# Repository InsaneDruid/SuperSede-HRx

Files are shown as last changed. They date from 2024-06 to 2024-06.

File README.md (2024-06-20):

# SuperSede-HRx - a HRx clone family
A 100% compatible replica of the HR40, HR40B &amp; HR80 graphics boards for the CBM PET lineup.

The SuperSede HRx are 100% compatible clones of the HR40, HR40B and HR80 graphics boards for the PET/CBM series computers from 1982, beginning with the dynamic board.
They implements all the features, including the high 320*200 pixel high resolution graphics that can be mixed standard text output on a per character base, the availability of the 8k of onboard RAM for Data usage and the possibility to use existing ROM expansion on the graphics board.

## The HR40 board for the non CRTC 40column dynamic PET lineup
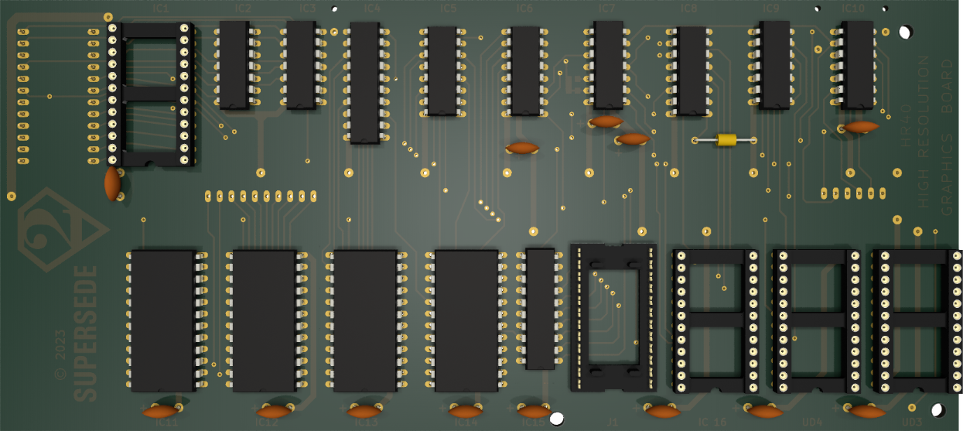
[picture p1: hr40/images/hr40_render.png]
HR40 render


[Schematic](https://github.com/InsaneDruid/SuperSede-HRx/blob/main/hr40/hr40.pdf "Schematic")  

[Bill of Materials](https://htmlpreview.github.io/?https://github.com/InsaneDruid/SuperSede-HRx/blob/main/hr40/bom/hr40_bom.html "Bill of Materials")

[Wire connections](https://github.com/InsaneDruid/SuperSede-HRx/blob/main/hr40/hr40_connections.pdf "Wire connections" )

* The connection to the Character ROM can be made with a standard DIP24 to ribbon cable adapter.

* The connection to UF8 can be made with the provided breakout adapter found in [adapter_uf8](https://github.com/InsaneDruid/SuperSede-HRx/blob/main/adapter_uf8/ "adapter_uf8").

## The HR40b board for the CRTC based 40column PET/CBM lineup
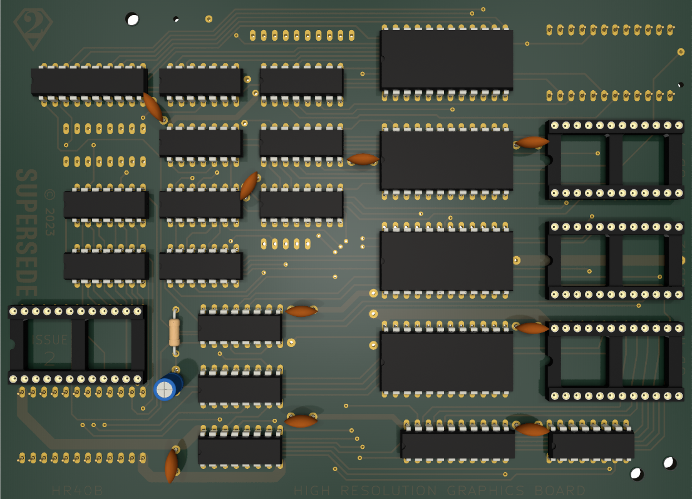
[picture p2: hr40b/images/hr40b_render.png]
HR40B render


[Schematic](https://github.com/InsaneDruid/SuperSede-HRx/blob/main/hr40b/hr40b.pdf "Schematic")  

[Bill of Materials](https://htmlpreview.github.io/?https://github.com/InsaneDruid/SuperSede-HRx/blob/main/hr40b/bom/hr40b_bom.html "Bill of Materials")

[Wire connections](https://github.com/InsaneDruid/SuperSede-HRx/blob/main/hr40b/hr40b_connections.pdf "Wire connections" )

* The connection to the CRTC can be made with the provided breakout adapter found in [adapter_crtc](https://github.com/InsaneDruid/SuperSede-HRx/blob/main/adapter_crtc/ "adapter_crtc").

## The HR80 board for the 80column CBM lineup (8032, 8032SK*, 8096)
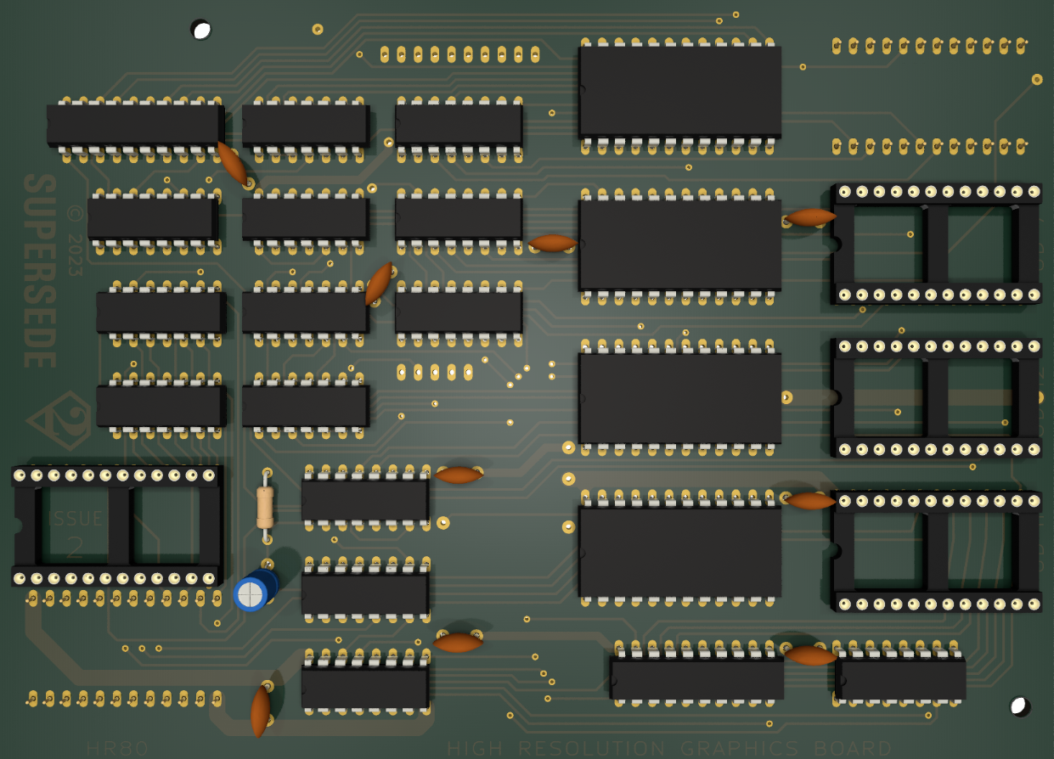
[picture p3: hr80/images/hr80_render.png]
HR80 render


[Schematic](https://github.com/InsaneDruid/SuperSede-HRx/blob/main/hr80/hr80.pdf "Schematic")  

[Bill of Materials](https://htmlpreview.github.io/?https://github.com/InsaneDruid/SuperSede-HRx/blob/main/hr80/bom/hr80_bom.html "Bill of Materials")

[Wire connections](https://github.com/InsaneDruid/SuperSede-HRx/blob/main/hr80/hr80_connections.pdf "Wire connections" )

* The connection to the CRTC can be made with the provided breakout adapter found in [adapter_crtc](https://github.com/InsaneDruid/SuperSede-HRx/blob/main/adapter_crtc/ "adapter_crtc").

## The SuperSede cards and Expansion ROMs
The SuperSede boards hav 8k of their own RAM which occupies memory locations 36864 to 45055 ($9000 to $AFFF). This is the Rom Expansion area, normally represented by sockets UD11 and UD12 (UD3 and UD4 for 9-inch PETs). 

When you power-up your computer the ROM sockets are enabled and the high resolution memory disabled. Thus Rom expansions can be used in standard text mode like normal.

## The Firmware
The firmware needed for the SuperSede cards consist of

* A modified CharRom (with inverted characters).
* A 4k ROM containing the EditorROM followed by the GRAPHIX software in the E900-EFFF area.

The Firmware and supporting tools are available on their own repository: [SuperSede-HRx-Software](https://github.com/InsaneDruid/SuperSede-HRx-Software/ "Firmware and tools for the SuperSede HRx boards ")

## The License
This work is licensed under a Creative Commons Attribution-ShareAlike 4.0 International License.   
See https://creativecommons.org/licenses/by-sa/4.0/.

## The Credits
This work would not have been possible without the help from a bunch of amazing people from [VzEkC e. V. forums](https://forum.classic-computing.de/forum/ "forum.classic-computing.de"). Many thanks go out to:

* *Andy Grady* - for the scans of a blank board that formed the backbone for this project, the construction of the first prototypes as well as writing the print routines and assembling the firmware for the cards.
* *Steve Gray* - for collecting a ton of information about the cards
* *CBM_Ba* and *Richy* - for prototyping, testing, feedback and general positive retrocomputing craziness

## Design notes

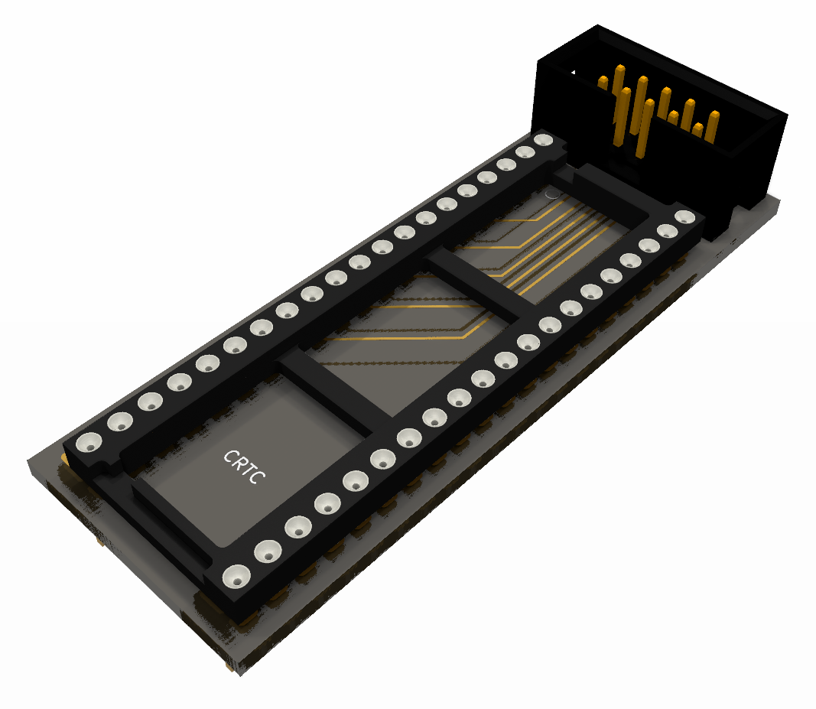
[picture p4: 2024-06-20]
adapter_crtc/images/adapter_crtc_render.png

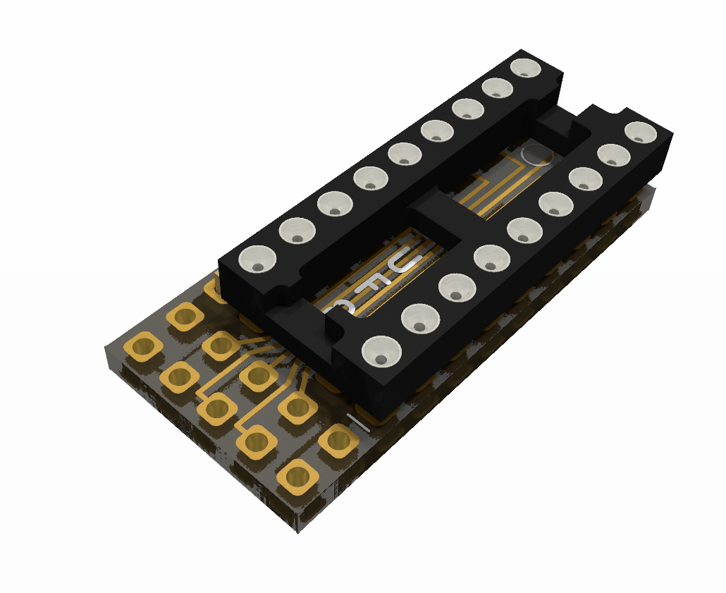
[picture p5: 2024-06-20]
adapter_uf8/images/adapter_uf8_render.png

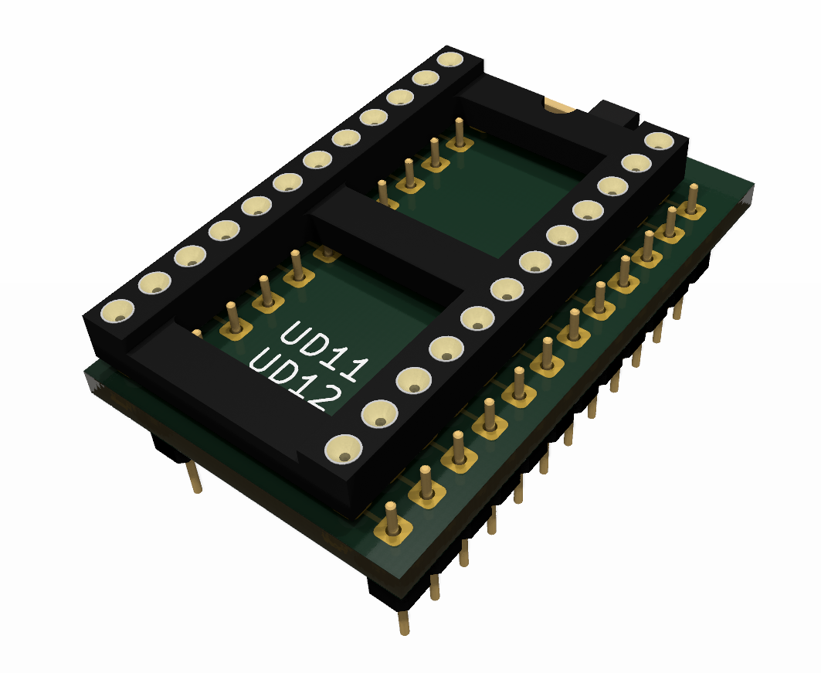
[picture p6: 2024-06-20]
adapter_roms_sk/images/adapter_roms_sk_render.png

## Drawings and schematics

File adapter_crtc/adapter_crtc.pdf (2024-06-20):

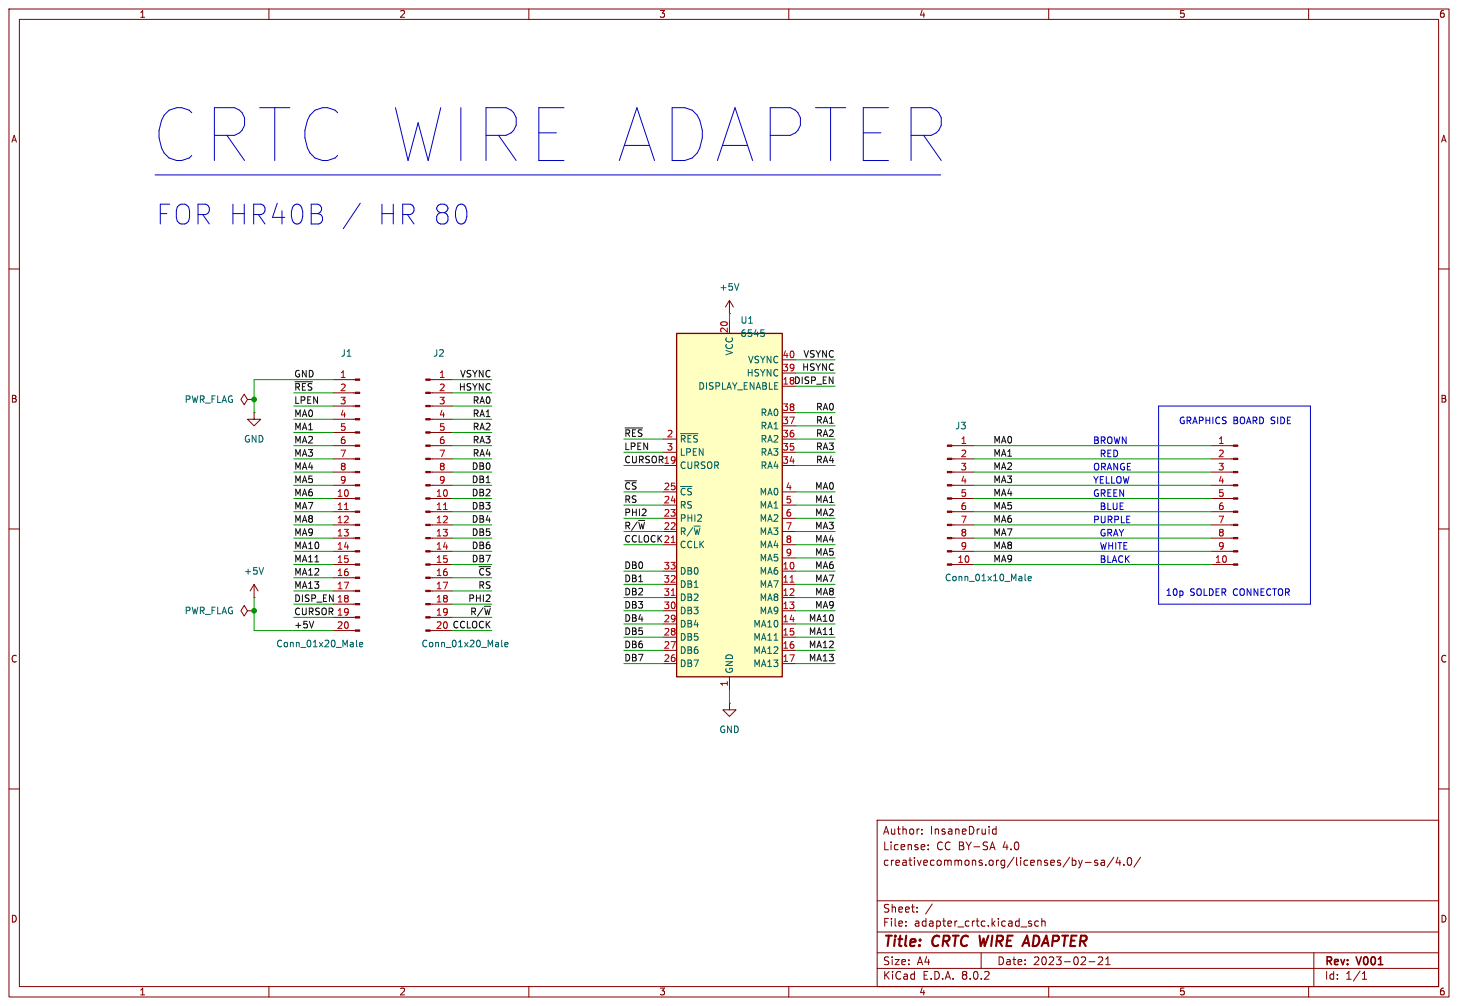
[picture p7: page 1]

BROWN CRTC WIRE ADAPTER

1 MA6 10 MA7 11 MA8 12 MA9 13 MA10 14 MA11 15 MA12 16 MA13 17 DISPLAY_ENABLE 18 CURSOR 19 ~{RES} 2 VCC 20 CCLK 21 R/~{W} 22 PHI2 23 RS 24 ~{CS} 25 DB7 26 DB6 27 DB5 28 DB4 29

Id: 1/1 Title: CRTC WIRE ADAPTER

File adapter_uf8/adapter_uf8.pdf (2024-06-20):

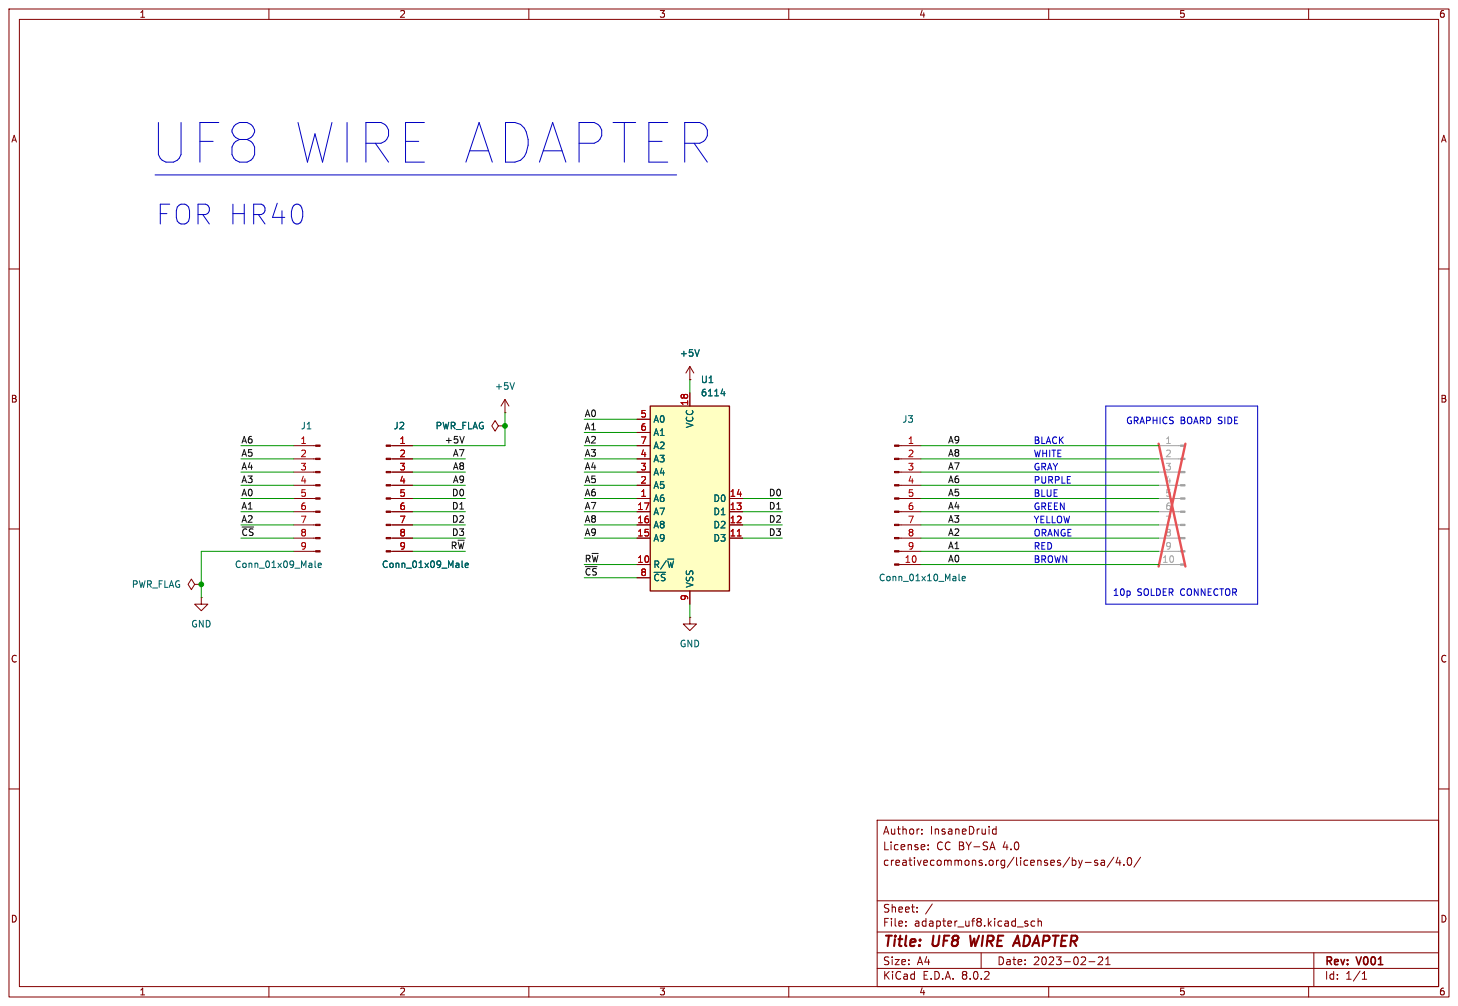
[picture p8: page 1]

10p SOLDER CONNECTOR GRAPHICS BOARD SIDE WHITE
BLACK

Id: 1/1 Title: UF8 WIRE ADAPTER

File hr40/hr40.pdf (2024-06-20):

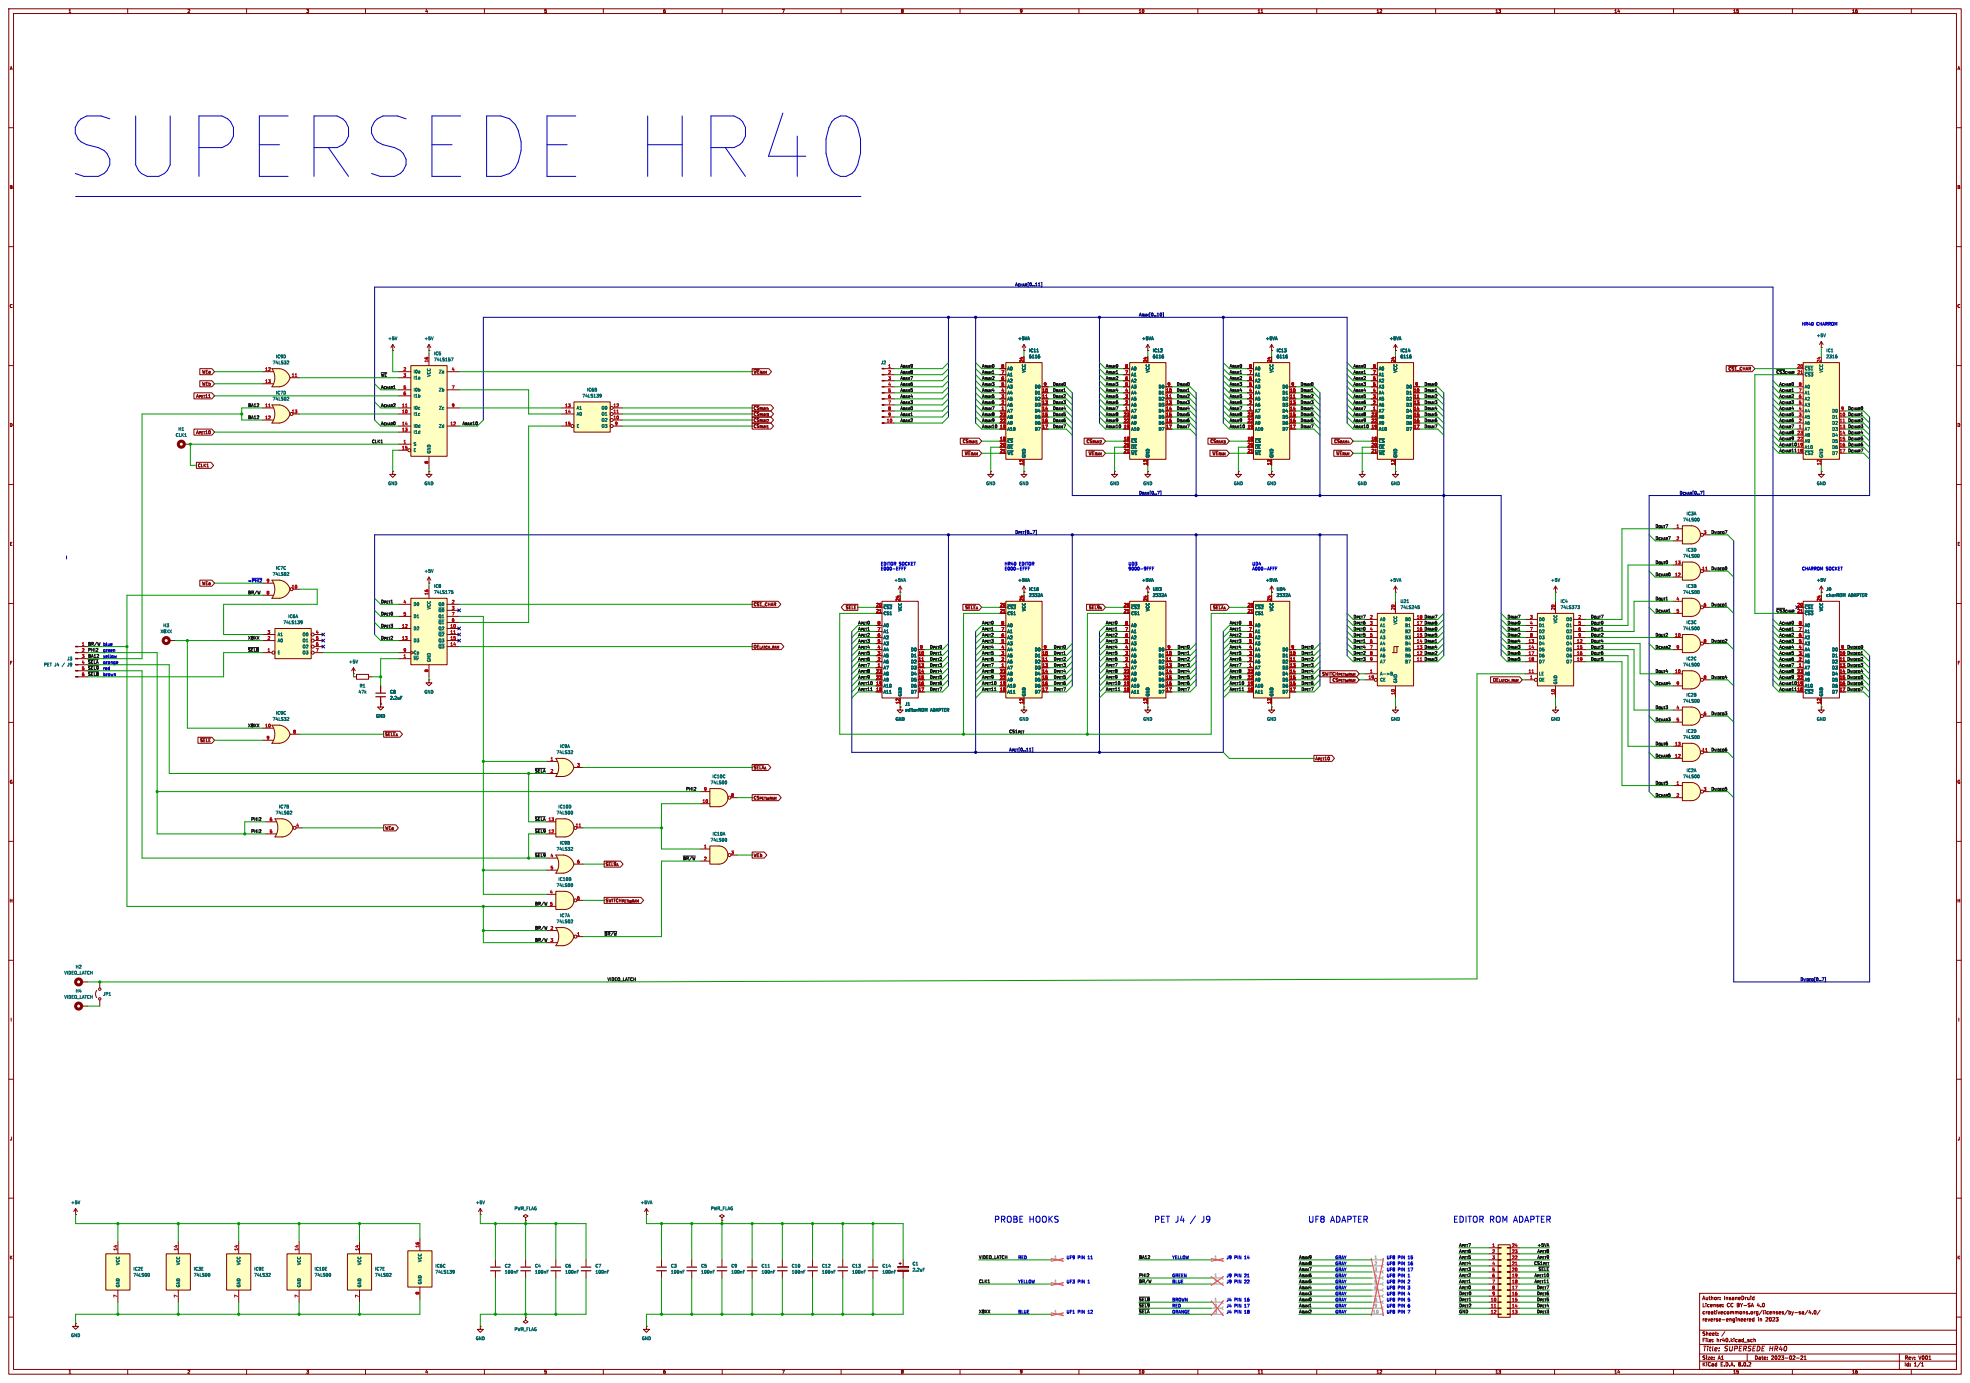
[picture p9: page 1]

UF3 PIN 1 RED PROBE HOOKS

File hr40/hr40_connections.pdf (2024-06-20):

# SUPERSEDE HR40 wire connections

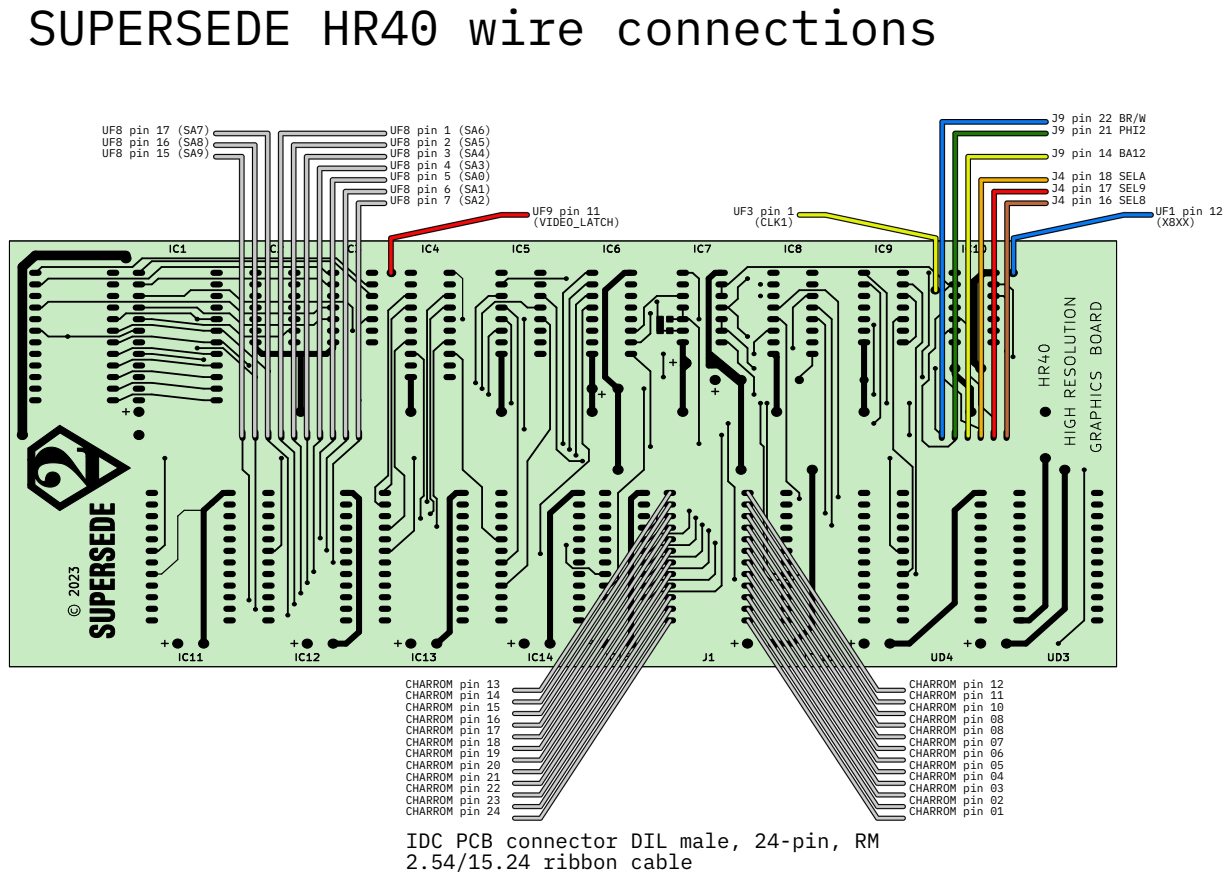
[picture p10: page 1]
UF8 pin 16 (SA8) UF8 pin 15 (SA9); UF8 pin 4 (SA3); J4 pin 18 SELA; UF8 pin 7 (SA2); J4 pin 16 SEL8; UF8 pin 17 (SA7); UF8 pin 5 (SA0); J9 pin 14 BA12; UF3 pin 1 (CLK1); J9 pin 22 BR/W; UF1 pin 12 (X8XX); UF8 pin 1 (SA6); UF9 pin 11 (VIDEO_LATCH); UF8 pin 3 (SA4); J9 pin 21 PHI2; UF8 pin 6 (SA1); J4 pin 17 SEL9; UF8 pin 2 (SA5)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

CHARROM pin 13
CHARROM pin 14
CHARROM pin 15
CHARROM pin 16
CHARROM pin 17
CHARROM pin 18
CHARROM pin 19
CHARROM pin 20
CHARROM pin 21
CHARROM pin 22
CHARROM pin 23
CHARROM pin 24
IDC PCB connector DIL male, 24-pin, RM
2.54/15.24 ribbon cable

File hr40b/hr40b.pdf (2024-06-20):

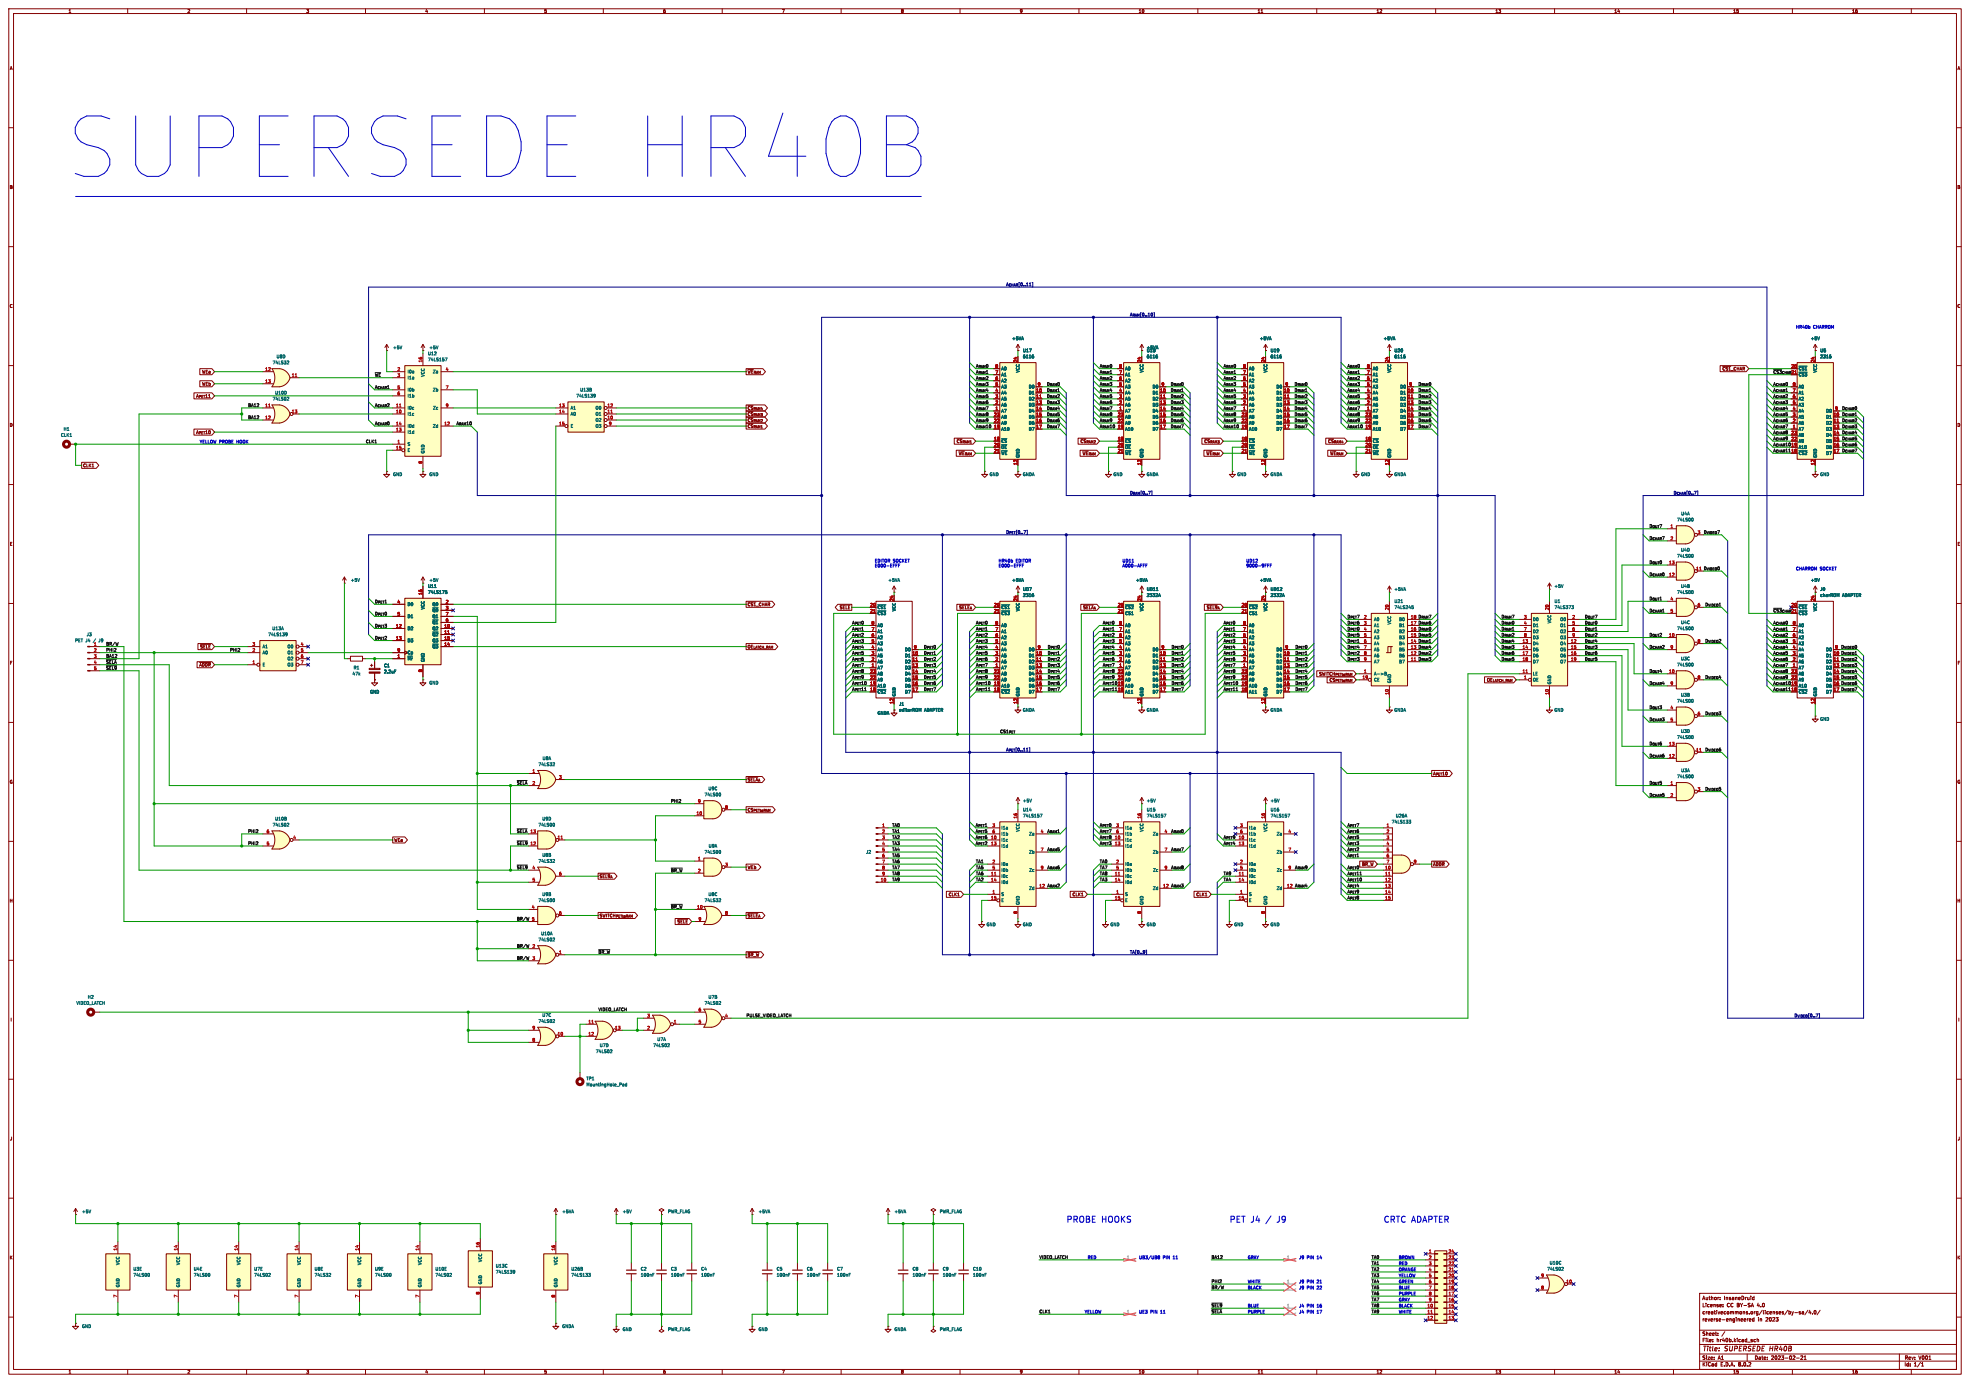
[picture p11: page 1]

editorROM ADAPTER VCC 14 GND

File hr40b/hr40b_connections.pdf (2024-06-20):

# SUPERSEDE HR40b wire connections

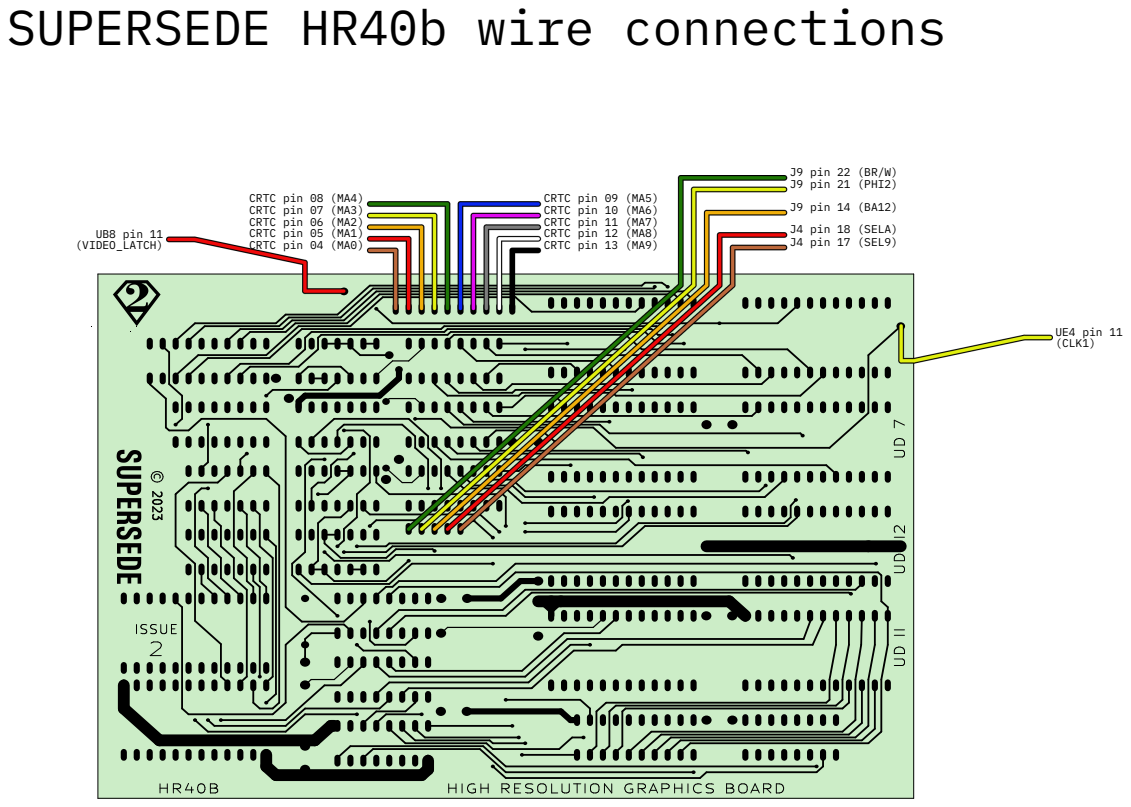
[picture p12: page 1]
J9 pin 21 (PHI2); J9 pin 14 (BA12); J4 pin 18 (SELA); CRTC pin 04 (MA0); J4 pin 17 (SEL9); UE4 pin 11 (CLK1); CRTC pin 13 (MA9); CRTC pin 12 (MA8); CRTC pin 11 (MA7); CRTC pin 07 (MA3); CRTC pin 10 (MA6); CRTC pin 08 (MA4); CRTC pin 06 (MA2); UB8 pin 11; CRTC pin 05 (MA1); (VIDEO_LATCH); CRTC pin 09 (MA5); J9 pin 22 (BR/W)

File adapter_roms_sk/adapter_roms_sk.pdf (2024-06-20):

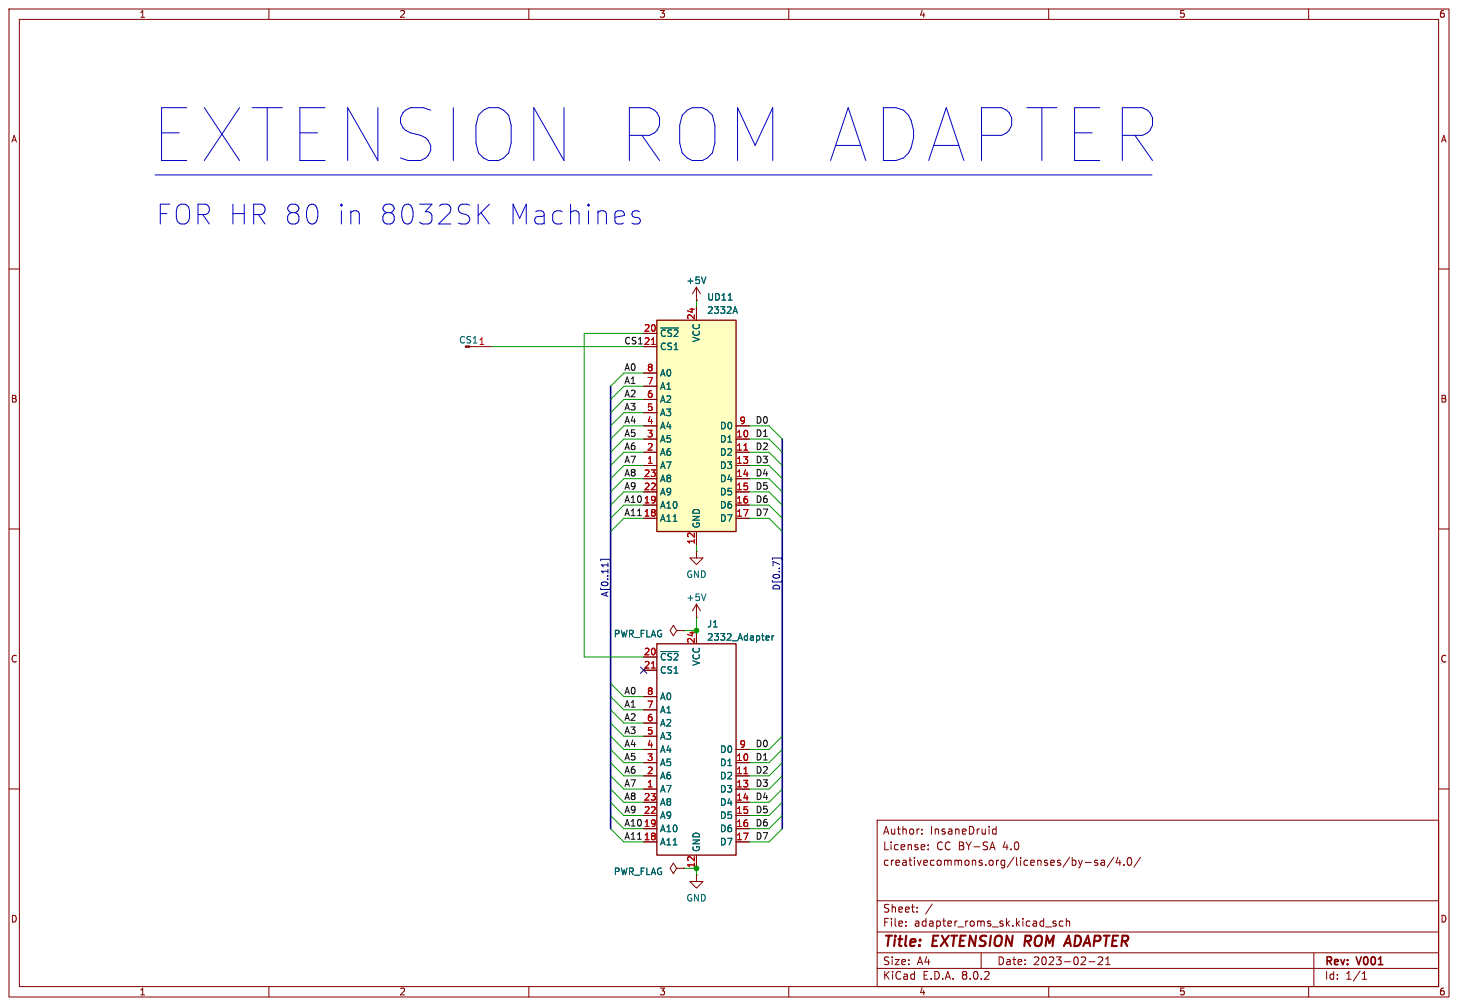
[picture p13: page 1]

Id: 1/1 Title: EXTENSION ROM ADAPTER

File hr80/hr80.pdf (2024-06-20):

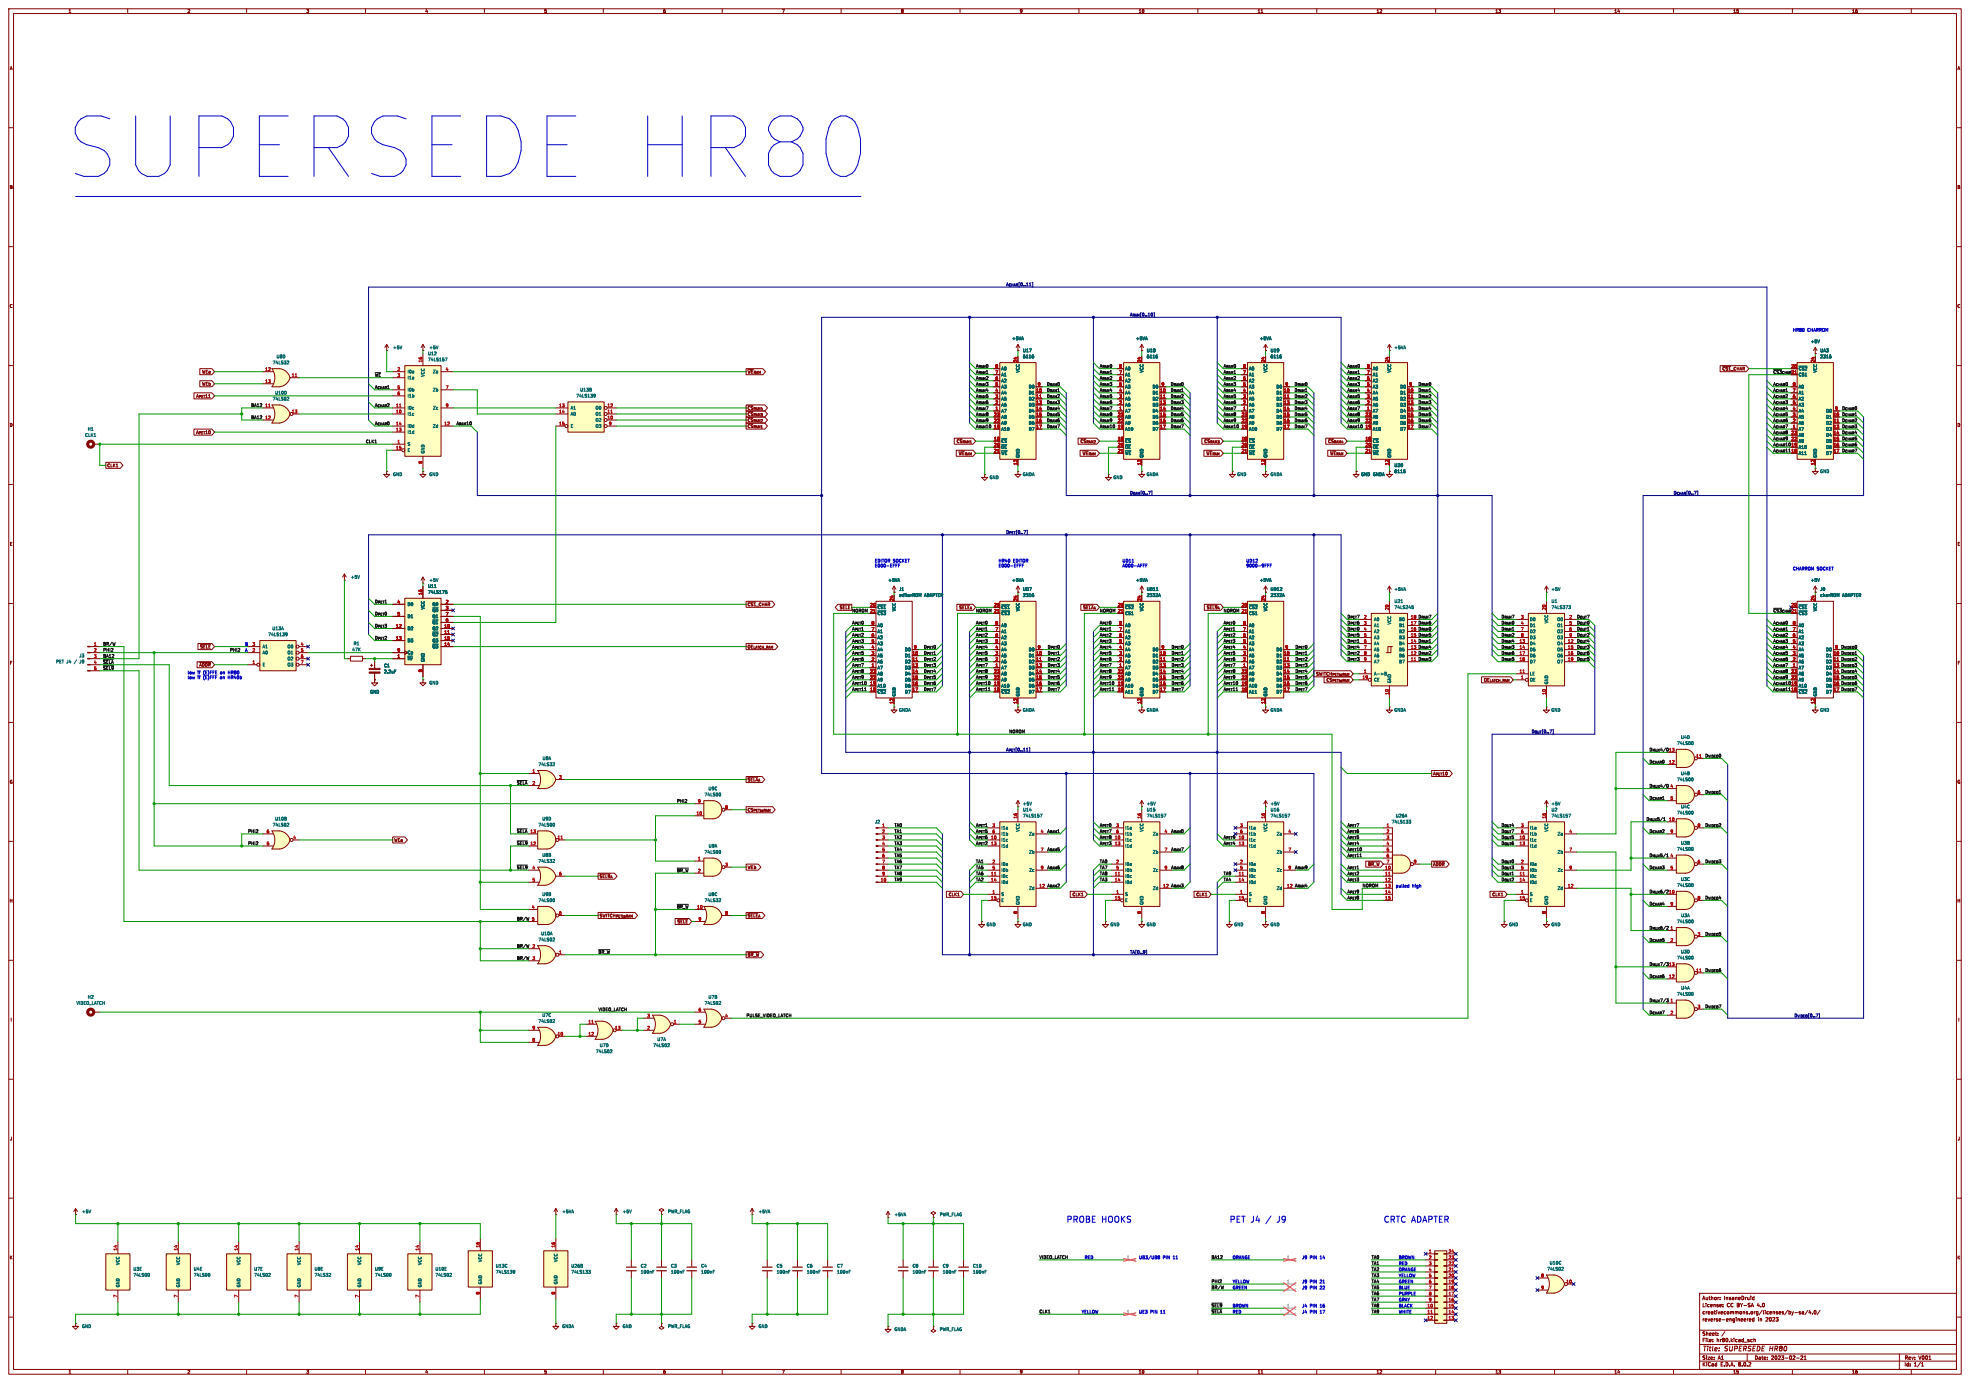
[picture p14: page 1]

~{ADDR}
low if (E)FFE on HR80

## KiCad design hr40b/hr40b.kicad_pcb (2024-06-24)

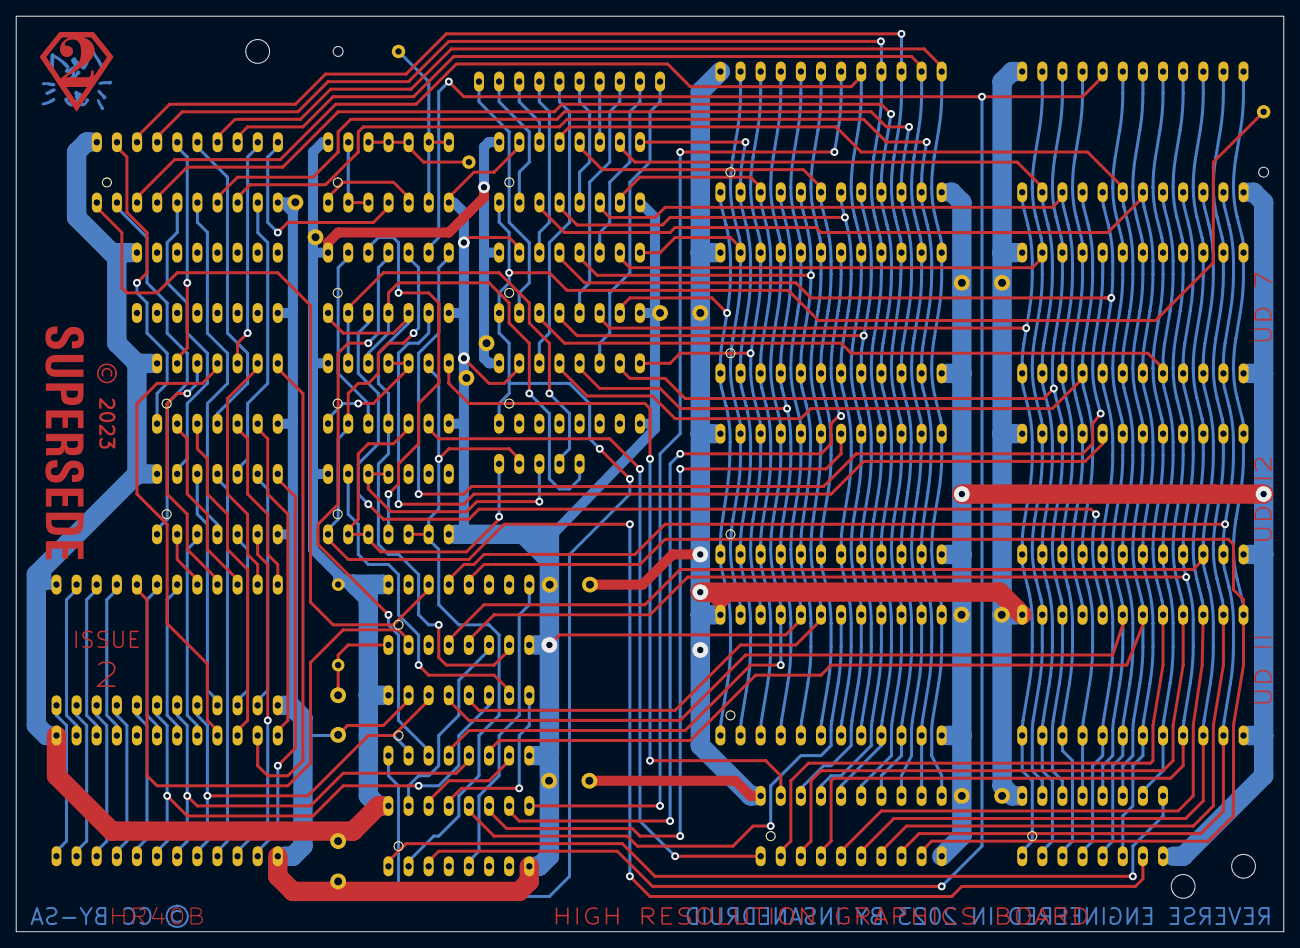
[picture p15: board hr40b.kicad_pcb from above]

Board: 2 copper layers, 160.0 x 115.6 mm, 47 parts (0 on the bottom side), 128 nets.

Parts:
C1: 2.2uF; CP_Radial_D10.0mm_P5.00mm
C2, C3, C4, C5, C6, C7, C8, C9, C10: 100nF; C_Disc_D7.5mm_W2.5mm_P5.08mm
H1: CLK1; PinHeader_1x01_P2.54mm_Vertical
H2: VIDEO_LATCH; PinHeader_1x01_P2.54mm_Vertical
J0: charROM ADAPTER; DIP-24_W15.24mm_Adapter
J1: editorROM ADAPTER; DIP-24_W15.24mm_Adapter
J2: PET CRTC; PinHeader_1x10_P2.54mm_Vertical
J3: PET J4 / J9; PinHeader_1x05_P2.54mm_Vertical
MH0, MH5: MountingHole_3mm
MH2: MountingHole_1.25mm
Mh4: MountingHole_3mm
R1: 47k; R_Axial_DIN0207_L6.3mm_D2.5mm_P10.16mm_Horizontal
RMH1: MountingHole_1.25mm
TP1: MountingHole_Pad; PinHeader_1x01_P2.54mm_Vertical
U1: 74LS373; DIP-20_W7.62mm_LongPads
U2: 74LS157; DIP-16_W7.62mm_LongPads_Empty
U3, U4, U9: 74LS00; DIP-14_W7.62mm_LongPads
U5: 2316; DIP-24_W15.24mm_Socket_LongPads
U7, U10: 74LS02; DIP-14_W7.62mm_LongPads
U8: 74LS32; DIP-14_W7.62mm_LongPads
U11: 74LS175; DIP-16_W7.62mm_LongPads
U12, U14, U15, U16: 74LS157; DIP-16_W7.62mm_LongPads
U13: 74LS139; DIP-16_W7.62mm_LongPads
U17, U18, U19, U20: 6116; DIP-24_W15.24mm_LongPads
U21: 74LS245; DIP-20_W7.62mm_LongPads
U26: 74LS133; DIP-16_W7.62mm_LongPads
UD7: 2316; DIP-24_W15.24mm_Socket_LongPads
UD11, UD12: 2332A; DIP-24_W15.24mm_Socket_LongPads

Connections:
+5V: C2.1, C3.1, C4.1, J0.24 (VCC), R1.1, U1.20 (VCC), U2.16 (VCC), U3.14 (VCC), U4.14 (VCC), U5.24 (VCC), U7.14 (VCC), U8.14 (VCC), U9.14 (VCC), U10.14 (VCC), U11.16 (VCC), U12.2 (I0a), U12.16 (VCC), U13.16 (VCC), U14.16 (VCC), U15.16 (VCC), U16.16 (VCC)
+5VA: C5.1, C6.1, C7.1, C8.1, C9.1, C10.1, J1.24 (VCC), U17.24 (VCC), U18.24 (VCC), U19.24 (VCC), U20.24 (VCC), U21.20 (VCC), U26.16 (VCC), UD7.24 (VCC), UD11.24 (VCC), UD12.24 (VCC)
/A_{CHAR}0: J0.8 (A0), U5.8 (A0), U12.14 (I0d)
/A_{CHAR}1: J0.7 (A1), U5.7 (A1), U12.5 (I0b)
/A_{CHAR}2: J0.6 (A2), U5.6 (A2), U12.11 (I0c)
/A_{CHAR}3: J0.5 (A3), U5.5 (A3)
/A_{CHAR}4: J0.4 (A4), U5.4 (A4)
/A_{CHAR}5: J0.3 (A5), U5.3 (A5)
/A_{CHAR}6: J0.2 (A6), U5.2 (A6)
/A_{CHAR}7: J0.1 (A7), U5.1 (A7)
/A_{CHAR}8: J0.23 (A8), U5.23 (A8)
/A_{CHAR}9: J0.22 (A9), U5.22 (A9)
/A_{CHAR}10: J0.19 (A10), U5.19 (A10)
/A_{CHAR}11: J0.18 (~CS2), U5.18 (~CS2)
/A_{PET}0: J1.8 (A0), U15.3 (I1a), U26.10, UD7.8 (A0), UD11.8 (A0), UD12.8 (A0)
/A_{PET}1: J1.7 (A1), U14.3 (I1a), U26.6, UD7.7 (A1), UD11.7 (A1), UD12.7 (A1)
/A_{PET}2: J1.6 (A2), U14.13 (I1d), U26.5, UD7.6 (A2), UD11.6 (A2), UD12.6 (A2)
/A_{PET}3: J1.5 (A3), U15.13 (I1d), U26.4, UD7.5 (A3), UD11.5 (A3), UD12.5 (A3)
/A_{PET}4: J1.4 (A4), U16.13 (I1d), U26.13, UD7.4 (A4), UD11.4 (A4), UD12.4 (A4)
/A_{PET}5: J1.3 (A5), U14.6 (I1b), U26.3, UD7.3 (A5), UD11.3 (A5), UD12.3 (A5)
/A_{PET}6: J1.2 (A6), U14.10 (I1c), U26.2, UD7.2 (A6), UD11.2 (A6), UD12.2 (A6)
/A_{PET}7: J1.1 (A7), U15.6 (I1b), U26.1, UD7.1 (A7), UD11.1 (A7), UD12.1 (A7)
/A_{PET}8: J1.23 (A8), U15.10 (I1c), U26.15, UD7.23 (A8), UD11.23 (A8), UD12.23 (A8)
/A_{PET}9: J1.22 (A9), U16.10 (I1c), U26.14, UD7.22 (A9), UD11.22 (A9), UD12.22 (A9)
/A_{RAM}0: U15.4 (Za), U17.8 (A0), U18.8 (A0), U19.8 (A0), U20.8 (A0)
/A_{RAM}1: U14.4 (Za), U17.7 (A1), U18.7 (A1), U19.7 (A1), U20.7 (A1)
/A_{RAM}2: U14.12 (Zd), U17.6 (A2), U18.6 (A2), U19.6 (A2), U20.6 (A2)
/A_{RAM}3: U15.12 (Zd), U17.5 (A3), U18.5 (A3), U19.5 (A3), U20.5 (A3)
/A_{RAM}4: U16.12 (Zd), U17.4 (A4), U18.4 (A4), U19.4 (A4), U20.4 (A4)
/A_{RAM}5: U14.7 (Zb), U17.3 (A5), U18.3 (A5), U19.3 (A5), U20.3 (A5)
/A_{RAM}6: U14.9 (Zc), U17.2 (A6), U18.2 (A6), U19.2 (A6), U20.2 (A6)
/A_{RAM}7: U15.7 (Zb), U17.1 (A7), U18.1 (A7), U19.1 (A7), U20.1 (A7)
/A_{RAM}8: U15.9 (Zc), U17.23 (A8), U18.23 (A8), U19.23 (A8), U20.23 (A8)
/A_{RAM}9: U16.9 (Zc), U17.22 (A9), U18.22 (A9), U19.22 (A9), U20.22 (A9)
/A_{RAM}10: U12.12 (Zd), U17.19 (A10), U18.19 (A10), U19.19 (A10), U20.19 (A10)
/BA12: J3.3, U10.11, U10.12
/BR/W: J3.1, U9.5, U10.2, U10.3
/CS1_{PET}: J1.21 (~CS3), UD7.21 (~CS3), UD11.21 (CS1), UD12.21 (CS1)
/D_{CHAR}0: U4.12, U5.9 (D0)
/D_{CHAR}1: U4.5, U5.10 (D1)
/D_{CHAR}2: U4.9, U5.11 (D2)
/D_{CHAR}3: U3.5, U5.13 (D3)
/D_{CHAR}4: U3.9, U5.14 (D4)
/D_{CHAR}5: U3.2, U5.15 (D5)
/D_{CHAR}6: U3.12, U5.16 (D6)
/D_{CHAR}7: U4.2, U5.17 (D7)
/D_{OUT}0: U1.5 (O1), U4.13
/D_{OUT}1: U1.6 (O2), U4.4
/D_{OUT}2: U1.9 (O3), U4.10
/D_{OUT}3: U1.15 (O5), U3.4
/D_{OUT}4: U1.12 (O4), U3.10
/D_{OUT}5: U1.19 (O7), U3.1
/D_{OUT}6: U1.16 (O6), U3.13
/D_{OUT}7: U1.2 (O0), U4.1
/D_{PET}0: J1.9 (D0), U11.5 (D1), U21.4 (A2), UD7.9 (D0), UD11.9 (D0), UD12.9 (D0)
/D_{PET}1: J1.10 (D1), U11.4 (D0), U21.6 (A4), UD7.10 (D1), UD11.10 (D1), UD12.10 (D1)
/D_{PET}2: J1.11 (D2), U11.13 (D3), U21.8 (A6), UD7.11 (D2), UD11.11 (D2), UD12.11 (D2)
/D_{PET}3: J1.13 (D3), U11.12 (D2), U21.9 (A7), UD7.13 (D3), UD11.13 (D3), UD12.13 (D3)
/D_{PET}4: J1.14 (D4), U21.7 (A5), UD7.14 (D4), UD11.14 (D4), UD12.14 (D4)
/D_{PET}5: J1.15 (D5), U21.5 (A3), UD7.15 (D5), UD11.15 (D5), UD12.15 (D5)
/D_{PET}6: J1.16 (D6), U21.3 (A1), UD7.16 (D6), UD11.16 (D6), UD12.16 (D6)
/D_{PET}7: J1.17 (D7), U21.2 (A0), UD7.17 (D7), UD11.17 (D7), UD12.17 (D7)
/D_{RAM}0: U1.4 (D1), U17.9 (D0), U18.9 (D0), U19.9 (D0), U20.9 (D0), U21.16 (B2)
/D_{RAM}1: U1.7 (D2), U17.10 (D1), U18.10 (D1), U19.10 (D1), U20.10 (D1), U21.14 (B4)
/D_{RAM}2: U1.8 (D3), U17.11 (D2), U18.11 (D2), U19.11 (D2), U20.11 (D2), U21.12 (B6)
/D_{RAM}3: U1.14 (D5), U17.13 (D3), U18.13 (D3), U19.13 (D3), U20.13 (D3), U21.11 (B7)
/D_{RAM}4: U1.13 (D4), U17.14 (D4), U18.14 (D4), U19.14 (D4), U20.14 (D4), U21.13 (B5)
/D_{RAM}5: U1.18 (D7), U17.15 (D5), U18.15 (D5), U19.15 (D5), U20.15 (D5), U21.15 (B3)
/D_{RAM}6: U1.17 (D6), U17.16 (D6), U18.16 (D6), U19.16 (D6), U20.16 (D6), U21.17 (B1)
/D_{RAM}7: U1.3 (D0), U17.17 (D7), U18.17 (D7), U19.17 (D7), U20.17 (D7), U21.18 (B0)
/D_{VIDEO}0: J0.9 (D0), U4.11
/D_{VIDEO}1: J0.10 (D1), U4.6
/D_{VIDEO}2: J0.11 (D2), U4.8
/D_{VIDEO}3: J0.13 (D3), U3.6
/D_{VIDEO}4: J0.14 (D4), U3.8
/D_{VIDEO}5: J0.15 (D5), U3.3
/D_{VIDEO}6: J0.16 (D6), U3.11
/D_{VIDEO}7: J0.17 (D7), U4.3
/PHI2: J3.2, U9.9, U10.5, U10.6, U13.2 (A0)
/PULSE_VIDEO_LATCH: U1.11 (LE), U7.4
/TA0: J2.1, U15.2 (I0a)
/TA1: J2.2, U14.2 (I0a)
/TA2: J2.3, U14.14 (I0d)
/TA3: J2.4, U15.14 (I0d)
/TA4: J2.5, U16.14 (I0d)
/TA5: J2.6, U14.5 (I0b)
/TA6: J2.7, U14.11 (I0c)
/TA7: J2.8, U15.5 (I0b)
/TA8: J2.9, U15.11 (I0c)
/TA9: J2.10, U16.11 (I0c)
/VIDEO_LATCH: H2.1, U7.6, U7.8, U7.9
/~CS3_{CHAR}: J0.21 (~CS3), U5.21 (~CS3)
/~SEL9: J3.5, U8.4, U9.12
/~SELA: J3.4, U8.2, U9.13
/~WE: U8.11, U12.3 (I1a)
A_{PET}10: J1.19 (A10), U12.13 (I1d), U26.12, UD7.19 (A10), UD11.19 (A10), UD12.19 (A10)
A_{PET}11: J1.18 (~CS2), U12.6 (I1b), U26.11, UD7.18 (~CS2), UD11.18 (A11), UD12.18 (A11)
CLK1: H1.1, U12.1 (S), U14.1 (S), U15.1 (S), U16.1 (S)
CS_{PETtoRAM}: U9.8, U21.19 (CE)
GND: C1.2, C2.2, C3.2, C4.2, C5.2, C6.2, C7.2, J0.12 (GND), U1.10 (GND), U2.8 (GND), U3.7 (GND), U4.7 (GND), U5.12 (GND), U7.7 (GND), U8.7 (GND), U9.7 (GND), U10.7 (GND), U11.8 (GND), U12.8 (GND), U12.15 (E), U13.8 (GND), U14.8 (GND), U14.15 (E), U15.8 (GND), U15.15 (E), U16.8 (GND), U16.15 (E), U17.20 (~OE), U18.20 (~OE), U19.20 (~OE), U20.20 (~OE)
GNDA: C8.2, C9.2, C10.2, J1.12 (GND), U17.12 (GND), U18.12 (GND), U19.12 (GND), U20.12 (GND), U21.10 (GND), U26.8 (GND), UD7.12 (GND), UD11.12 (GND), UD12.12 (GND)
unnamed: TP1.1, U7.10, U7.11, U7.12
unnamed: U7.1, U7.5
unnamed: U7.2, U7.3, U7.13
unnamed: U9.1, U9.10, U9.11
unnamed: U11.9 (Cp), U13.5 (O1)
unnamed: U8.1, U8.5, U9.4, U11.7 (Q1)
unnamed: C1.1, R1.2, U11.1 (~Mr)
unnamed: U11.6 (~Q1), U13.15 (E)
unnamed: U10.13, U12.10 (I1c)
unnamed: U12.7 (Zb), U13.14 (A0)
unnamed: U12.9 (Zc), U13.13 (A1)
OE_{LATCH_RAM}: U1.1 (OE), U11.14 (~Q3)
SWITCH_{PETtoRAM}: U9.6, U21.1 (A->B)
WEa: U8.12, U10.4
WEb: U8.13, U9.3
~ADDR: U13.1 (E), U26.9
~BR_W: U8.10, U9.2, U10.1, U26.7
~CS1_CHAR: U5.20 (~CS1), U11.2 (Q0)
~CS_{RAM1}: U13.9 (O3), U17.18 (~CS)
~CS_{RAM2}: U13.10 (O2), U18.18 (~CS)
~CS_{RAM3}: U13.11 (O1), U19.18 (~CS)
~CS_{RAM4}: U13.12 (O0), U20.18 (~CS)
~SEL9_{A}: U8.6, UD12.20 (~CS2)
~SELA_{A}: U8.3, UD11.20 (~CS2)
~SELE: J1.20 (~CS1), U8.9, U13.3 (A1)
~SELE_{A}: U8.8, UD7.20 (~CS1)
~WE_{RAM}: U12.4 (Za), U17.21 (~WE), U18.21 (~WE), U19.21 (~WE), U20.21 (~WE)

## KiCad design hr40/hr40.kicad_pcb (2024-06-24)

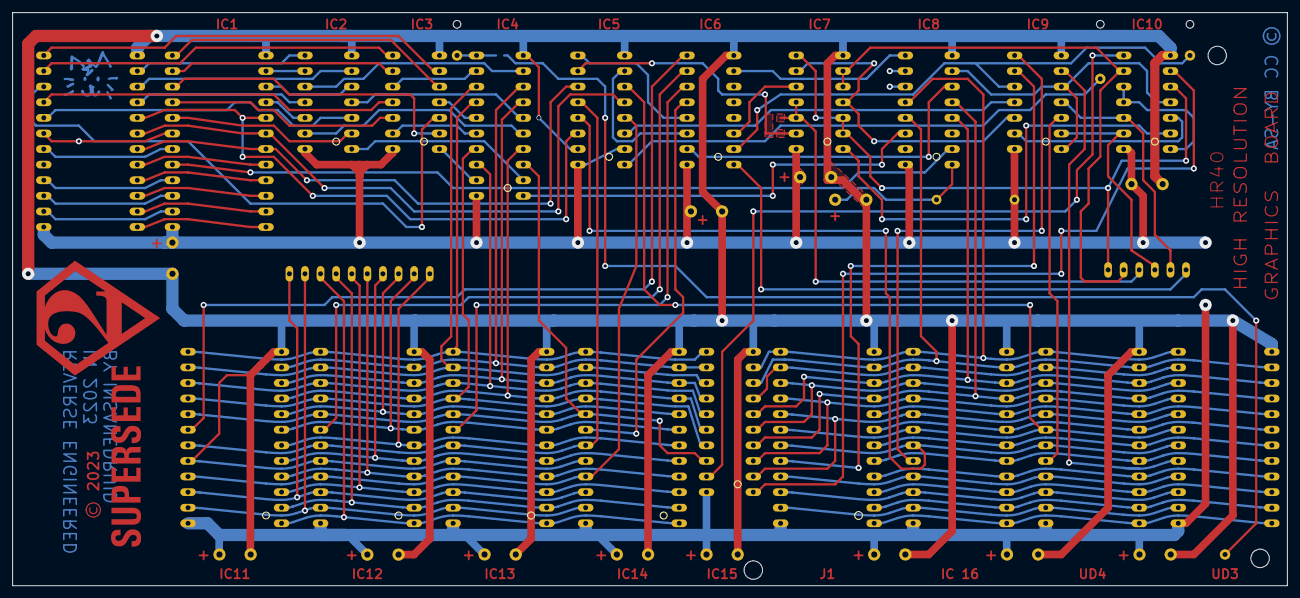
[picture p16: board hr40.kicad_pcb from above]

Board: 2 copper layers, 207.6 x 93.3 mm, 47 parts (1 on the bottom side), 116 nets.

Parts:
C2, C3, C4, C5, C6, C7, C9, C10, C11, C12, C13, C14: 100nF; C_Disc_D7.5mm_W2.5mm_P5.08mm
C8: 2.2uF; C_Disc_D7.5mm_W2.5mm_P5.08mm
H1: CLK1; PinHeader_1x01_P2.54mm_Vertical
H2, H4: VIDEO_LATCH; PinHeader_1x01_P2.54mm_Vertical
H3: X8XX; PinHeader_1x01_P2.54mm_Vertical
IC1: 2316; DIP-24_W15.24mm_Socket_LongPads
IC2, IC3, IC10: 74LS00; DIP-14_W7.62mm_LongPads
IC4: 74LS373; DIP-20_W7.62mm_LongPads
IC5: 74LS157; DIP-16_W7.62mm_LongPads
IC6: 74LS139; DIP-16_W7.62mm_LongPads
IC7: 74LS02; DIP-14_W7.62mm_LongPads
IC8: 74LS175; DIP-16_W7.62mm_LongPads
IC9: 74LS32; DIP-14_W7.62mm_LongPads
IC11, IC12, IC13, IC14: 6116; DIP-24_W15.24mm_LongPads
IC16: 2332A; DIP-24_W15.24mm_Socket_LongPads
J0: charROM ADAPTER; DIP-24_W15.24mm_Adapter
J1: editorROM ADAPTER; DIP-24_W15.24mm_WireAdapter
J2: PET F8; PinHeader_1x10_P2.54mm_Vertical
J3: PET J4 / J9; PinHeader_1x06_P2.54mm_Vertical
JP1: Jumper_2_Open; SolderJumper-2_P1.3mm_Open_RoundedPad1.0x1.5mm
MH0, MH1, MH2: MountingHole_1.25mm
MH3, MH4, MH5: MountingHole_3mm
R1: 47k; R_Axial_DIN0207_L6.3mm_D2.5mm_P12.70mm_Horizontal
U21: 74LS245; DIP-20_W7.62mm_LongPads
UD3, UD4: 2332A; DIP-24_W15.24mm_Socket_LongPads

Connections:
+5V: C2.1, C4.1, C6.1, C7.1, IC1.24 (VCC), IC2.14 (VCC), IC3.14 (VCC), IC4.20 (VCC), IC5.2 (I0a), IC5.16 (VCC), IC6.16 (VCC), IC7.14 (VCC), IC8.16 (VCC), IC9.14 (VCC), IC10.14 (VCC), J0.24 (VCC), R1.1
+5VA: C3.1, C5.1, C9.1, C10.1, C11.1, C12.1, C13.1, C14.1, IC11.24 (VCC), IC12.24 (VCC), IC13.24 (VCC), IC14.24 (VCC), IC16.24 (VCC), J1.24 (VCC), U21.20 (VCC), UD3.24 (VCC), UD4.24 (VCC)
/A_{CHAR}0: IC1.8 (A0), IC5.14 (I0d), J0.8 (A0)
/A_{CHAR}1: IC1.7 (A1), IC5.5 (I0b), J0.7 (A1)
/A_{CHAR}2: IC1.6 (A2), IC5.11 (I0c), J0.6 (A2)
/A_{CHAR}3: IC1.5 (A3), J0.5 (A3)
/A_{CHAR}4: IC1.4 (A4), J0.4 (A4)
/A_{CHAR}5: IC1.3 (A5), J0.3 (A5)
/A_{CHAR}6: IC1.2 (A6), J0.2 (A6)
/A_{CHAR}7: IC1.1 (A7), J0.1 (A7)
/A_{CHAR}8: IC1.23 (A8), J0.23 (A8)
/A_{CHAR}9: IC1.22 (A9), J0.22 (A9)
/A_{CHAR}10: IC1.19 (A10), J0.19 (A10)
/A_{CHAR}11: IC1.18 (~CS2), J0.18 (~CS2)
/A_{PET}0: IC16.8 (A0), J1.8 (A0), UD3.8 (A0), UD4.8 (A0)
/A_{PET}1: IC16.7 (A1), J1.7 (A1), UD3.7 (A1), UD4.7 (A1)
/A_{PET}2: IC16.6 (A2), J1.6 (A2), UD3.6 (A2), UD4.6 (A2)
/A_{PET}3: IC16.5 (A3), J1.5 (A3), UD3.5 (A3), UD4.5 (A3)
/A_{PET}4: IC16.4 (A4), J1.4 (A4), UD3.4 (A4), UD4.4 (A4)
/A_{PET}5: IC16.3 (A5), J1.3 (A5), UD3.3 (A5), UD4.3 (A5)
/A_{PET}6: IC16.2 (A6), J1.2 (A6), UD3.2 (A6), UD4.2 (A6)
/A_{PET}7: IC16.1 (A7), J1.1 (A7), UD3.1 (A7), UD4.1 (A7)
/A_{PET}8: IC16.23 (A8), J1.23 (A8), UD3.23 (A8), UD4.23 (A8)
/A_{PET}9: IC16.22 (A9), J1.22 (A9), UD3.22 (A9), UD4.22 (A9)
/A_{RAM}0: IC11.8 (A0), IC12.8 (A0), IC13.8 (A0), IC14.8 (A0), J2.8
/A_{RAM}1: IC11.7 (A1), IC12.7 (A1), IC13.7 (A1), IC14.7 (A1), J2.9
/A_{RAM}2: IC11.6 (A2), IC12.6 (A2), IC13.6 (A2), IC14.6 (A2), J2.10
/A_{RAM}3: IC11.5 (A3), IC12.5 (A3), IC13.5 (A3), IC14.5 (A3), J2.7
/A_{RAM}4: IC11.4 (A4), IC12.4 (A4), IC13.4 (A4), IC14.4 (A4), J2.6
/A_{RAM}5: IC11.3 (A5), IC12.3 (A5), IC13.3 (A5), IC14.3 (A5), J2.5
/A_{RAM}6: IC11.2 (A6), IC12.2 (A6), IC13.2 (A6), IC14.2 (A6), J2.4
/A_{RAM}7: IC11.1 (A7), IC12.1 (A7), IC13.1 (A7), IC14.1 (A7), J2.3
/A_{RAM}8: IC11.23 (A8), IC12.23 (A8), IC13.23 (A8), IC14.23 (A8), J2.2
/A_{RAM}9: IC11.22 (A9), IC12.22 (A9), IC13.22 (A9), IC14.22 (A9), J2.1
/A_{RAM}10: IC5.12 (Zd), IC11.19 (A10), IC12.19 (A10), IC13.19 (A10), IC14.19 (A10)
/BA12: IC7.11, IC7.12, J3.3
/BR/W: IC7.2, IC7.3, IC7.8, IC10.5, J3.1
/CS1_{PET}: IC16.21 (CS1), J1.21 (CS1), UD3.21 (CS1), UD4.21 (CS1)
/D_{CHAR}0: IC1.9 (D0), IC3.12
/D_{CHAR}1: IC1.10 (D1), IC3.5
/D_{CHAR}2: IC1.11 (D2), IC3.9
/D_{CHAR}3: IC1.13 (D3), IC2.5
/D_{CHAR}4: IC1.14 (D4), IC2.9
/D_{CHAR}5: IC1.15 (D5), IC2.2
/D_{CHAR}6: IC1.16 (D6), IC2.12
/D_{CHAR}7: IC1.17 (D7), IC3.2
/D_{OUT}0: IC3.13, IC4.5 (O1)
/D_{OUT}1: IC3.4, IC4.6 (O2)
/D_{OUT}2: IC3.10, IC4.9 (O3)
/D_{OUT}3: IC2.4, IC4.15 (O5)
/D_{OUT}4: IC2.10, IC4.12 (O4)
/D_{OUT}5: IC2.1, IC4.19 (O7)
/D_{OUT}6: IC2.13, IC4.16 (O6)
/D_{OUT}7: IC3.1, IC4.2 (O0)
/D_{PET}0: IC8.5 (D1), IC16.9 (D0), J1.9 (D0), U21.4 (A2), UD3.9 (D0), UD4.9 (D0)
/D_{PET}1: IC8.4 (D0), IC16.10 (D1), J1.10 (D1), U21.6 (A4), UD3.10 (D1), UD4.10 (D1)
/D_{PET}2: IC8.13 (D3), IC16.11 (D2), J1.11 (D2), U21.8 (A6), UD3.11 (D2), UD4.11 (D2)
/D_{PET}3: IC8.12 (D2), IC16.13 (D3), J1.13 (D3), U21.9 (A7), UD3.13 (D3), UD4.13 (D3)
/D_{PET}4: IC16.14 (D4), J1.14 (D4), U21.7 (A5), UD3.14 (D4), UD4.14 (D4)
/D_{PET}5: IC16.15 (D5), J1.15 (D5), U21.5 (A3), UD3.15 (D5), UD4.15 (D5)
/D_{PET}6: IC16.16 (D6), J1.16 (D6), U21.3 (A1), UD3.16 (D6), UD4.16 (D6)
/D_{PET}7: IC16.17 (D7), J1.17 (D7), U21.2 (A0), UD3.17 (D7), UD4.17 (D7)
/D_{RAM}0: IC4.4 (D1), IC11.9 (D0), IC12.9 (D0), IC13.9 (D0), IC14.9 (D0), U21.16 (B2)
/D_{RAM}1: IC4.7 (D2), IC11.10 (D1), IC12.10 (D1), IC13.10 (D1), IC14.10 (D1), U21.14 (B4)
/D_{RAM}2: IC4.8 (D3), IC11.11 (D2), IC12.11 (D2), IC13.11 (D2), IC14.11 (D2), U21.12 (B6)
/D_{RAM}3: IC4.14 (D5), IC11.13 (D3), IC12.13 (D3), IC13.13 (D3), IC14.13 (D3), U21.11 (B7)
/D_{RAM}4: IC4.13 (D4), IC11.14 (D4), IC12.14 (D4), IC13.14 (D4), IC14.14 (D4), U21.13 (B5)
/D_{RAM}5: IC4.18 (D7), IC11.15 (D5), IC12.15 (D5), IC13.15 (D5), IC14.15 (D5), U21.15 (B3)
/D_{RAM}6: IC4.17 (D6), IC11.16 (D6), IC12.16 (D6), IC13.16 (D6), IC14.16 (D6), U21.17 (B1)
/D_{RAM}7: IC4.3 (D0), IC11.17 (D7), IC12.17 (D7), IC13.17 (D7), IC14.17 (D7), U21.18 (B0)
/D_{VIDEO}0: IC3.11, J0.9 (D0)
/D_{VIDEO}1: IC3.6, J0.10 (D1)
/D_{VIDEO}2: IC3.8, J0.11 (D2)
/D_{VIDEO}3: IC2.6, J0.13 (D3)
/D_{VIDEO}4: IC2.8, J0.14 (D4)
/D_{VIDEO}5: IC2.3, J0.15 (D5)
/D_{VIDEO}6: IC2.11, J0.16 (D6)
/D_{VIDEO}7: IC3.3, J0.17 (D7)
/PHI2: IC7.5, IC7.6, IC10.9, J3.2
/VIDEO_LATCH: H2.1, IC4.11 (LE), JP1.2 (B)
/X8XX: H3.1, IC6.2 (A0), IC9.10
/~BR/W: IC7.1, IC10.2
/~CS3_{CHAR}: IC1.21 (~CS3), J0.21 (~CS3)
/~SEL8: IC6.1 (E), J3.6
/~SEL9: IC9.4, IC10.12, J3.5
/~SELA: IC9.2, IC10.13, J3.4
/~WE: IC5.3 (I1a), IC9.11
A_{PET}10: IC5.13 (I1d), IC16.19 (A10), J1.19 (A10), UD3.19 (A10), UD4.19 (A10)
A_{PET}11: IC5.6 (I1b), IC16.18 (A11), J1.18 (A11), UD3.18 (A11), UD4.18 (A11)
CLK1: H1.1, IC5.1 (S)
CS_{PETtoRAM}: IC10.8, U21.19 (CE)
GND: C2.2, C3.2, C4.2, C5.2, C6.2, C7.2, C8.2, C9.2, C10.2, C11.2, C12.2, C13.2, C14.2, IC1.12 (GND), IC2.7 (GND), IC3.7 (GND), IC4.10 (GND), IC5.8 (GND), IC5.15 (E), IC6.8 (GND), IC7.7 (GND), IC8.8 (GND), IC9.7 (GND), IC10.7 (GND), IC11.12 (GND), IC11.20 (~OE), IC12.12 (GND), IC12.20 (~OE), IC13.12 (GND), IC13.20 (~OE), IC14.12 (GND), IC14.20 (~OE), IC16.12 (GND), J0.12 (GND), J1.12 (GND), U21.10 (GND), UD3.12 (GND), UD4.12 (GND)
unnamed: IC5.10 (I1c), IC7.13
unnamed: IC5.7 (Zb), IC6.14 (A0)
unnamed: IC5.9 (Zc), IC6.13 (A1)
unnamed: IC6.3 (A1), IC7.10
unnamed: IC6.7 (O3), IC8.9 (Cp)
unnamed: IC6.15 (E), IC8.6 (~Q1)
unnamed: IC8.7 (Q1), IC9.1, IC9.5, IC10.4
unnamed: C8.1, IC8.1 (~Mr), R1.2
unnamed: IC10.1, IC10.10, IC10.11
unnamed: H4.1, JP1.1 (A)
OE_{LATCH_RAM}: IC4.1 (OE), IC8.14 (~Q3)
SWITCH_{PETtoRAM}: IC10.6, U21.1 (A->B)
WEa: IC7.4, IC7.9, IC9.12
WEb: IC9.13, IC10.3
~CS1_CHAR: IC1.20 (~CS1), IC8.2 (Q0)
~CS_{RAM1}: IC6.9 (O3), IC11.18 (~CS)
~CS_{RAM2}: IC6.10 (O2), IC12.18 (~CS)
~CS_{RAM3}: IC6.11 (O1), IC13.18 (~CS)
~CS_{RAM4}: IC6.12 (O0), IC14.18 (~CS)
~SEL9_{A}: IC9.6, UD3.20 (~CS2)
~SELA_{A}: IC9.3, UD4.20 (~CS2)
~SELE: IC9.9, J1.20 (~CS2)
~SELE_{A}: IC9.8, IC16.20 (~CS2)
~WE_{RAM}: IC5.4 (Za), IC11.21 (~WE), IC12.21 (~WE), IC13.21 (~WE), IC14.21 (~WE)

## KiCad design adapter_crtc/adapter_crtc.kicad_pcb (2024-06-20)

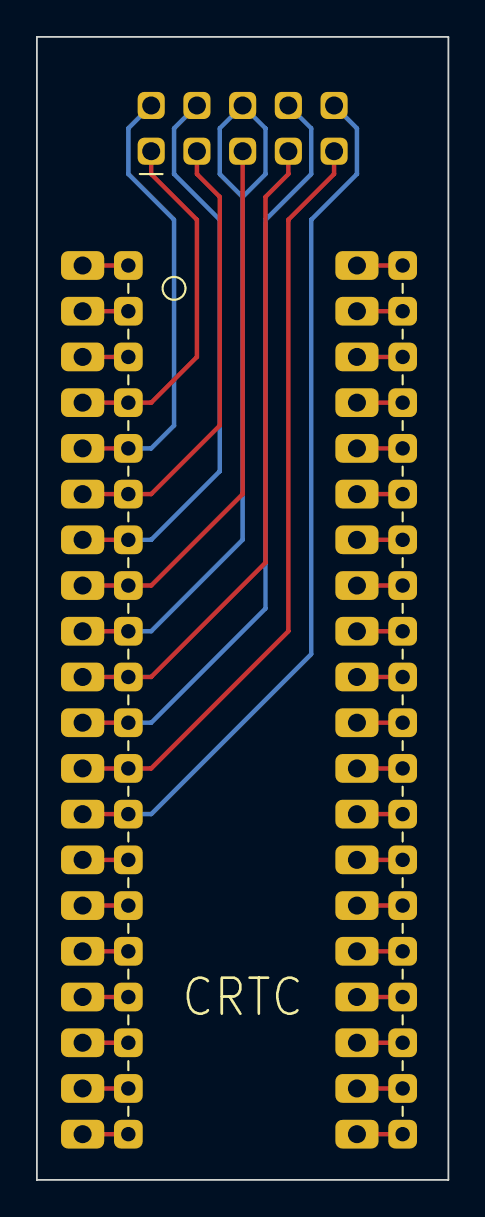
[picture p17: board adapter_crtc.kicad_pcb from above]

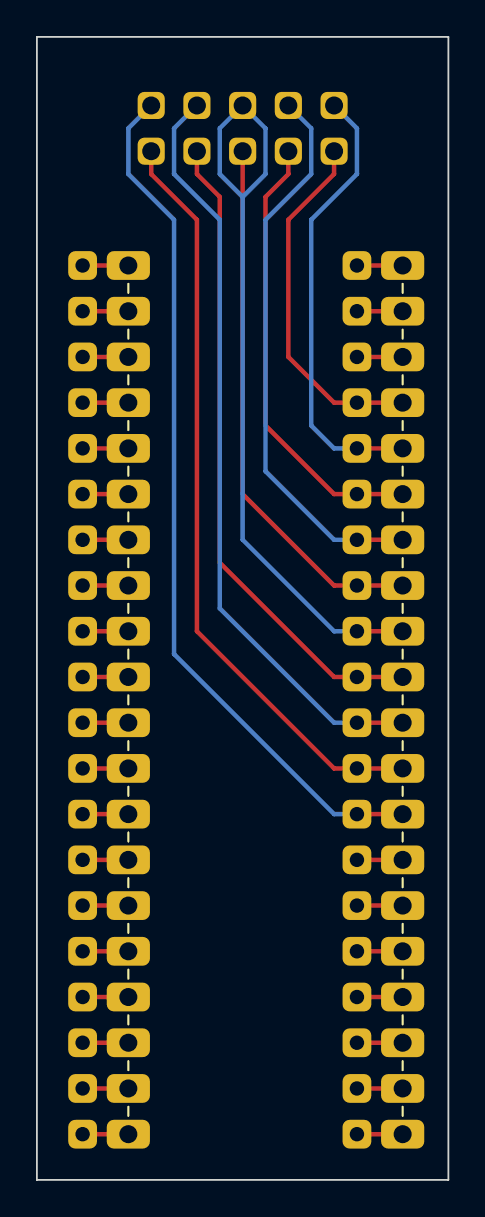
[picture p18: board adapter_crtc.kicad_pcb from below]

Board: 2 copper layers, 22.9 x 63.5 mm, 4 parts (2 on the bottom side), 40 nets.

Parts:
J1, J2: Conn_01x20_Male; PinHeader_1x20_P2.54mm_Vertical
J3: Conn_01x10_Male; Conn_02_05_Odd_Even
U1: 6545; DIP-40_W15.24mm_Socket

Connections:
+5V: J1.20, U1.20 (VCC)
/CCLOCK: J2.20, U1.21 (CCLK)
/CURSOR: J1.19, U1.19 (CURSOR)
/DB0: J2.8, U1.33 (DB0)
/DB1: J2.9, U1.32 (DB1)
/DB2: J2.10, U1.31 (DB2)
/DB3: J2.11, U1.30 (DB3)
/DB4: J2.12, U1.29 (DB4)
/DB5: J2.13, U1.28 (DB5)
/DB6: J2.14, U1.27 (DB6)
/DB7: J2.15, U1.26 (DB7)
/DISP_EN: J1.18, U1.18 (DISPLAY_ENABLE)
/HSYNC: J2.2, U1.39 (HSYNC)
/LPEN: J1.3, U1.3 (LPEN)
/MA0: J1.4, J3.1, U1.4 (MA0)
/MA1: J1.5, J3.2, U1.5 (MA1)
/MA2: J1.6, J3.3, U1.6 (MA2)
/MA3: J1.7, J3.4, U1.7 (MA3)
/MA4: J1.8, J3.5, U1.8 (MA4)
/MA5: J1.9, J3.6, U1.9 (MA5)
/MA6: J1.10, J3.7, U1.10 (MA6)
/MA7: J1.11, J3.8, U1.11 (MA7)
/MA8: J1.12, J3.9, U1.12 (MA8)
/MA9: J1.13, J3.10, U1.13 (MA9)
/MA10: J1.14, U1.14 (MA10)
/MA11: J1.15, U1.15 (MA11)
/MA12: J1.16, U1.16 (MA12)
/MA13: J1.17, U1.17 (MA13)
/PHI2: J2.18, U1.23 (PHI2)
/RA0: J2.3, U1.38 (RA0)
/RA1: J2.4, U1.37 (RA1)
/RA2: J2.5, U1.36 (RA2)
/RA3: J2.6, U1.35 (RA3)
/RA4: J2.7, U1.34 (RA4)
/RS: J2.17, U1.24 (RS)
/R/~W: J2.19, U1.22 (R/~W)
/VSYNC: J2.1, U1.40 (VSYNC)
/~CS: J2.16, U1.25 (~CS)
/~RES: J1.2, U1.2 (~RES)
GND: J1.1, U1.1 (GND)

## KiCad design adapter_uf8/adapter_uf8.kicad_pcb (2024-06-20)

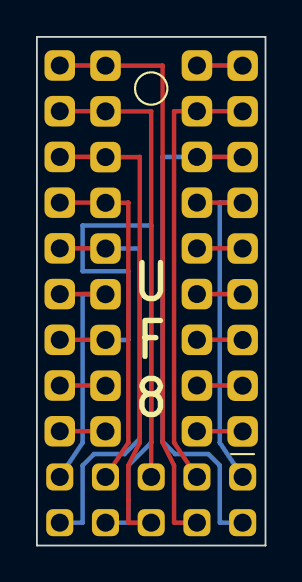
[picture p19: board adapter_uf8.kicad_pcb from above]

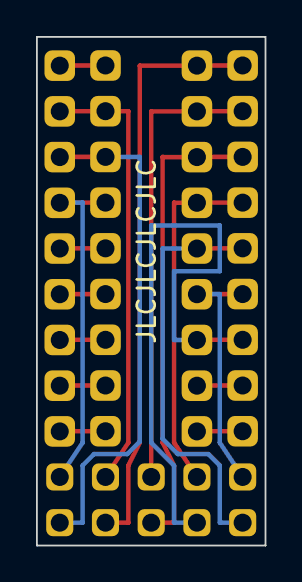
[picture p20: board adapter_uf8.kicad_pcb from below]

Board: 2 copper layers, 12.7 x 28.3 mm, 4 parts (2 on the bottom side), 18 nets.

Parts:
J1, J2: Conn_01x09_Male; PinHeader_1x09_P2.54mm_Vertical
J3: Conn_01x10_Male; Solderpad_02_05_Odd_Even
U1: 6114; DIP-18_W7.62mm_Socket

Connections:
+5V: J2.1, U1.18 (VCC)
/A0: J1.5, J3.10, U1.5 (A0)
/A1: J1.6, J3.9, U1.6 (A1)
/A2: J1.7, J3.8, U1.7 (A2)
/A3: J1.4, J3.7, U1.4 (A3)
/A4: J1.3, J3.6, U1.3 (A4)
/A5: J1.2, J3.5, U1.2 (A5)
/A6: J1.1, J3.4, U1.1 (A6)
/A7: J2.2, J3.3, U1.17 (A7)
/A8: J2.3, J3.2, U1.16 (A8)
/A9: J2.4, J3.1, U1.15 (A9)
/D0: J2.5, U1.14 (D0)
/D1: J2.6, U1.13 (D1)
/D2: J2.7, U1.12 (D2)
/D3: J2.8, U1.11 (D3)
/R~W: J2.9, U1.10 (R/~W)
/~CS: J1.8, U1.8 (~CS)
GND: J1.9, U1.9 (VSS)

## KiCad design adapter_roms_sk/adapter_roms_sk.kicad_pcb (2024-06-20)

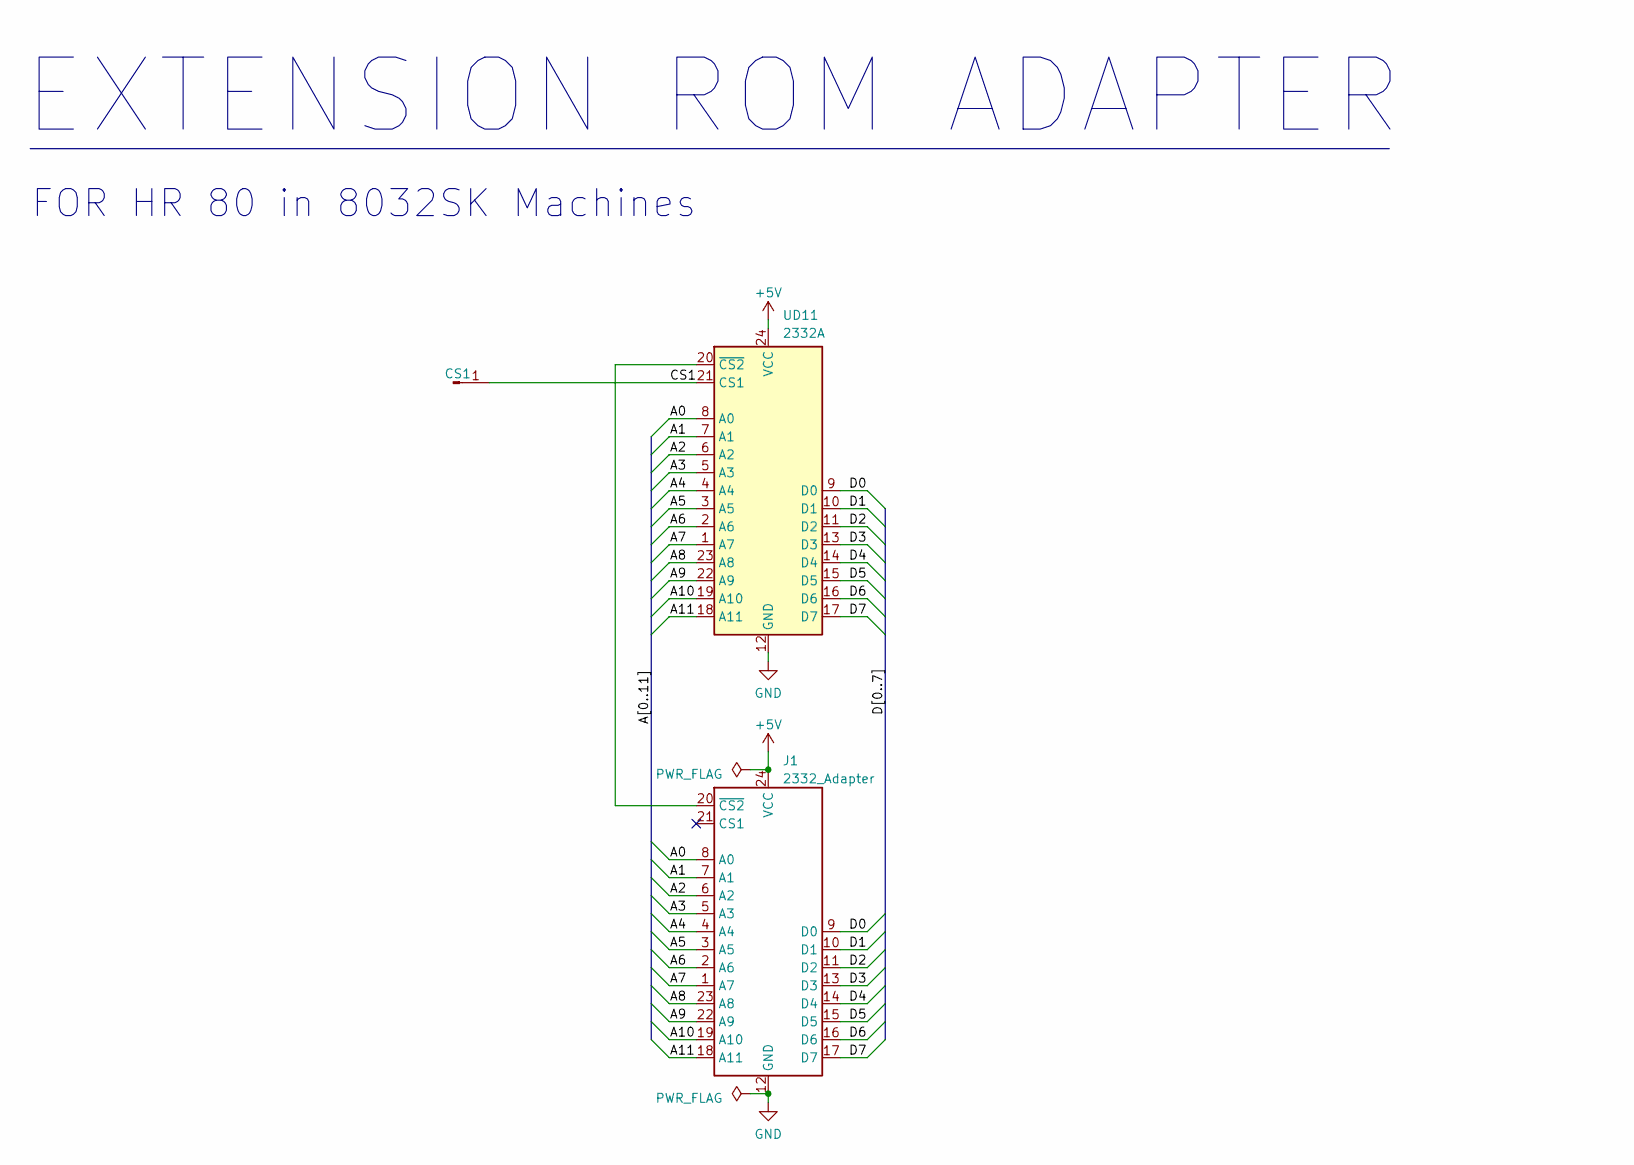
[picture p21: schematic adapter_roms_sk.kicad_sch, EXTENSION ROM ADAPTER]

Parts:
CS1: Conn_01x01_Pin; PinHeader_1x01_P2.54mm_Horizontal
J1: 2332_Adapter; DIP-24_W15.24mm_Adapter_Rectangularpads
UD11: 2332A; DIP-24_W15.24mm_Socket_RectangularPads

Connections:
+5V: J1.24 (VCC), UD11.24 (VCC)
/A0: J1.8 (A0), UD11.8 (A0)
/A1: J1.7 (A1), UD11.7 (A1)
/A2: J1.6 (A2), UD11.6 (A2)
/A3: J1.5 (A3), UD11.5 (A3)
/A4: J1.4 (A4), UD11.4 (A4)
/A5: J1.3 (A5), UD11.3 (A5)
/A6: J1.2 (A6), UD11.2 (A6)
/A7: J1.1 (A7), UD11.1 (A7)
/A8: J1.23 (A8), UD11.23 (A8)
/A9: J1.22 (A9), UD11.22 (A9)
/A10: J1.19 (A10), UD11.19 (A10)
/A11: J1.18 (A11), UD11.18 (A11)
/CS1: CS1.1, UD11.21 (CS1)
/D0: J1.9 (D0), UD11.9 (D0)
/D1: J1.10 (D1), UD11.10 (D1)
/D2: J1.11 (D2), UD11.11 (D2)
/D3: J1.13 (D3), UD11.13 (D3)
/D4: J1.14 (D4), UD11.14 (D4)
/D5: J1.15 (D5), UD11.15 (D5)
/D6: J1.16 (D6), UD11.16 (D6)
/D7: J1.17 (D7), UD11.17 (D7)
GND: J1.12 (GND), UD11.12 (GND)
unnamed: J1.20 (~CS2), UD11.20 (~CS2)

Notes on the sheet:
EXTENSION ROM ADAPTER
FOR HR 80 in 8032SK Machines

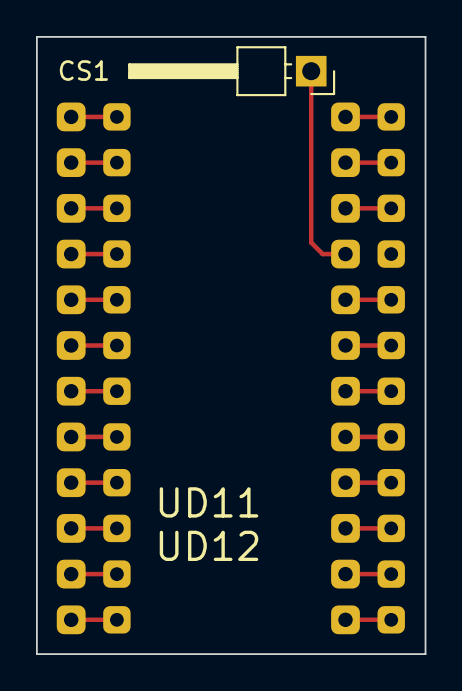
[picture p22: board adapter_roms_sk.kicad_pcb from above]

Board: 2 copper layers, 21.6 x 34.3 mm, 3 parts (0 on the bottom side), 24 nets.

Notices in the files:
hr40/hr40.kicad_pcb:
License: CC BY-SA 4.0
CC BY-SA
